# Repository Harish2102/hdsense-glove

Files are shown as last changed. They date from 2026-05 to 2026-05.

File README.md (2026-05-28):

<!-- markdownlint-disable MD041 -->
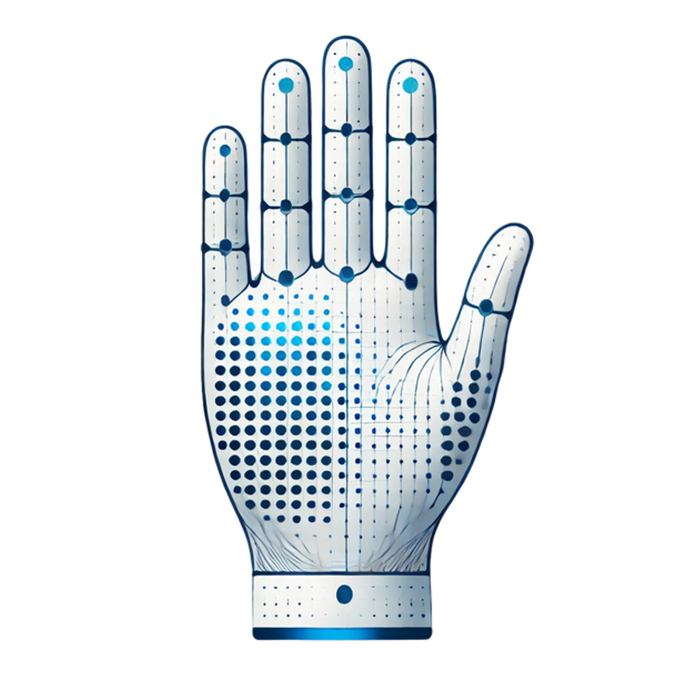
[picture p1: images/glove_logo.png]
HDSense Glove


# HDSense Glove

A high-density 32×32 pressure-sensing glove for prosthetics and haptic feedback

*Johns Hopkins University · Advanced Instruments and Systems · Fall 2024*
*Advised by Dr. Nitish Thakor and Arik Slepyan · Neuroengineering and Biomedical Instrumentation Lab*

---

## Overview

The HDSense Glove maps the full tactile surface of a hand using a **32×32 TDMA sensor array** - 1,024 individual pressure points per glove - streaming real-time contact data over serial. Designed for prosthetic hands, robotic manipulation, and human-computer interaction.

**Key specs:**

- 1,024 pressure sensors per glove (32×32 grid)
- **1000 Hz** frame rate, **20ms** latency
- **88% accuracy** detecting objects via compressed sensing
- **18× faster** than traditional raster scanning (Slepyan et al., 2024)
- Teensy 4.1 microcontroller, low-power flex-PCB design

---

## PCB Design

The glove uses a custom flex-PCB shaped to the anatomy of an average male hand (220mm length). Copper traces follow natural glove cuts with a flexible thumb extension. 32 row output pins are driven sequentially via TDMA, with a 5-bit MUX selecting across 32 columns - reducing 1,024 connections to a single analog readout channel.

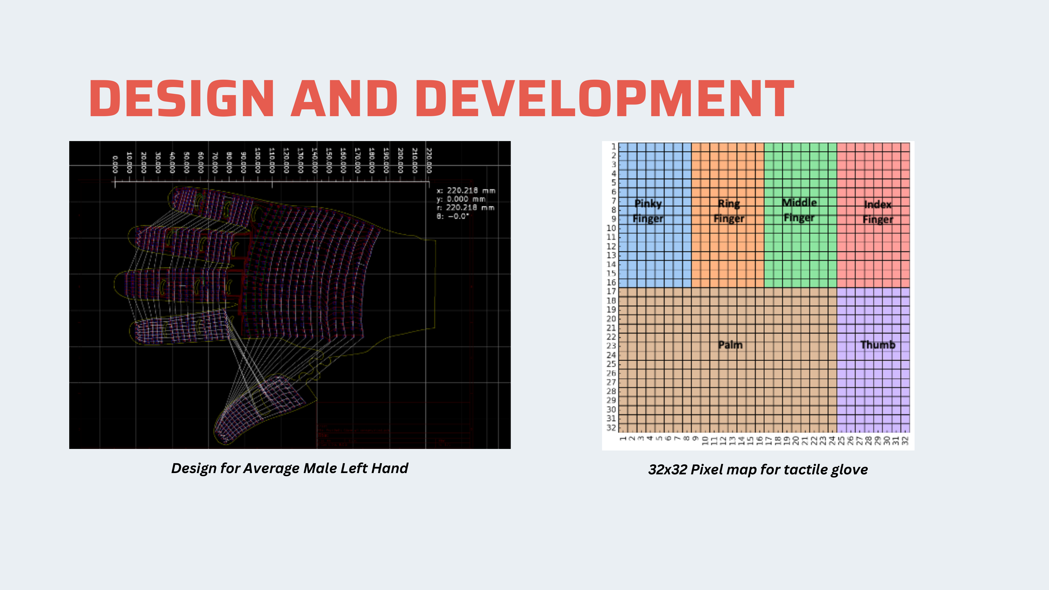
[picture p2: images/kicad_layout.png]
KiCad PCB Layout and Sensor Pixel Map


Left: KiCad flex-PCB layout shaped to the left hand geometry | Right: 32×32 sensor pixel map with finger and palm zones

The PCB was designed in KiCad with separate left-hand (LH) and right-hand (RH) variants. KiCad source files: [`hardware/LH/`](hardware/LH/) and [`hardware/RH/`](hardware/RH/)

---

## Firmware

`firmware/tdma_32x32_foot.ino` - compiled for **Teensy 4.1**

Performs a full 32×32 raster scan per loop using TDMA, outputs all 1,024 values as a comma-separated serial stream per frame. Uses `FASTRUN` and `digitalWriteFast` for maximum scan speed.

```cpp
for (int i = 0; i < 32; i++) {       // activate row
  for (int j = 0; j < 32; j++) {     // step through mux columns
    values[idx++] = analogRead(A0);  // read pressure
  }
}
```

---

## Project Poster

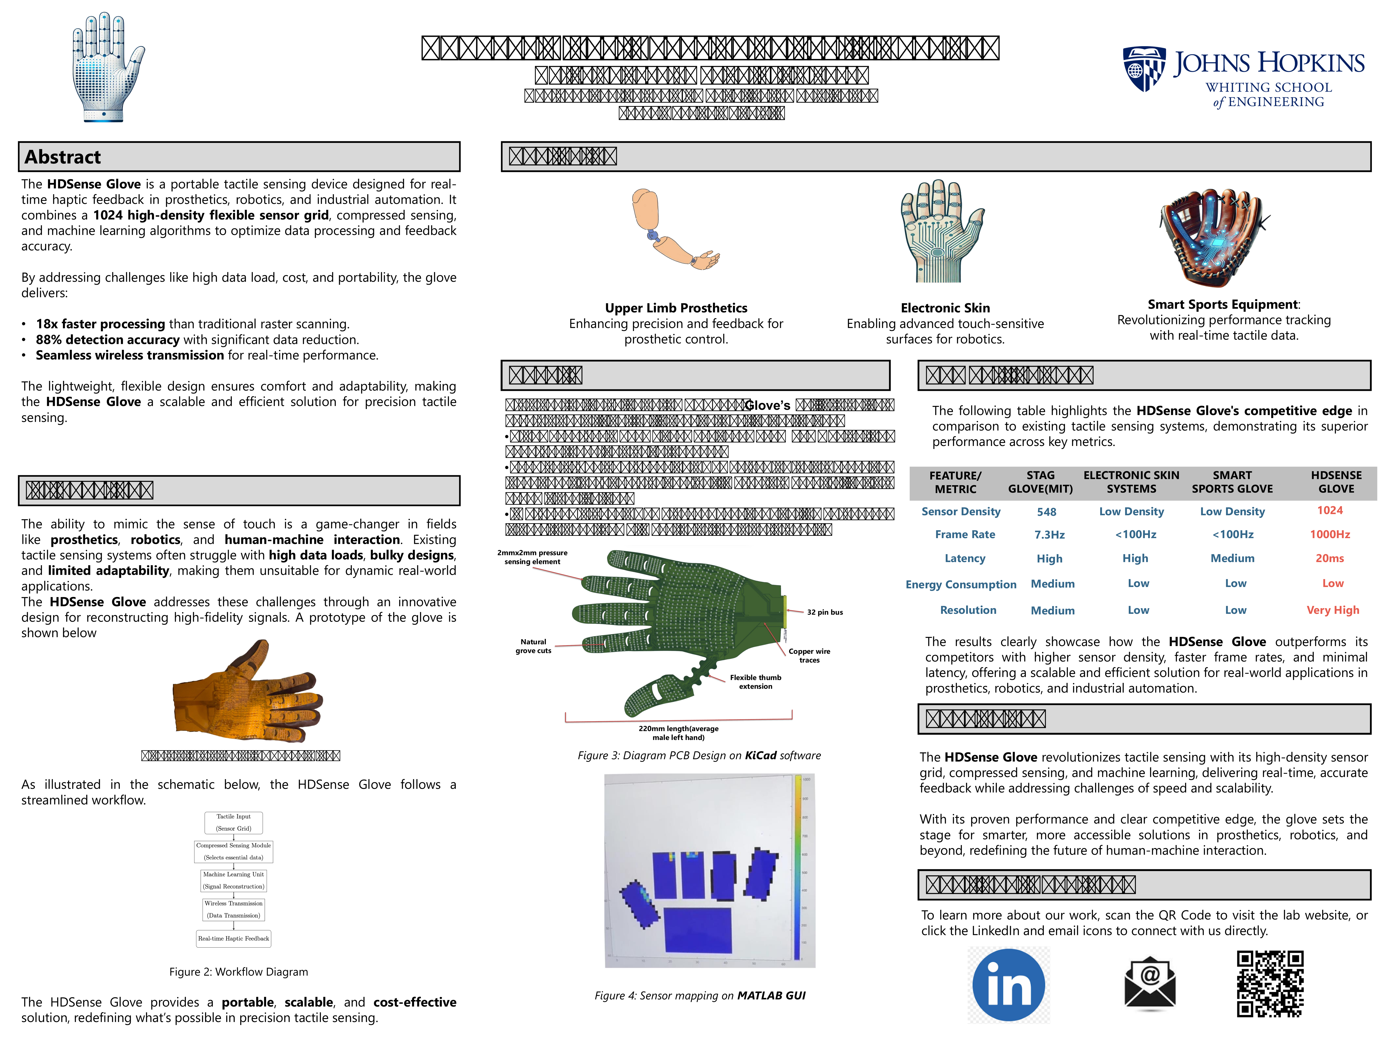
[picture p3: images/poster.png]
HDSense Glove Project Poster


Full project poster - includes KiCad PCB rendering (Fig. 3) and MATLAB sensor heatmap visualization (Fig. 4)

---

## Docs

| Document | Description |
| --- | --- |
| [Final Pitch Deck](docs/HDSense%20Glove%20Final%20Pitch.pdf) | Product pitch and system overview |
| [Project Poster](docs/Harish_Poster_Final.pdf) | Full project summary poster |

---

Harish Balasubramanian · Johns Hopkins University

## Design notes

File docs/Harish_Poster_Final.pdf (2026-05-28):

# HDSense Glove: Redesigning Tactile Sensing

## Harish Balasubramanian, Arik Slepyan

Neuroengineering and Biomedical Instrumentation Lab Johns Hopkins University

## Conclusions

The HDSense Glove revolutionizes tactile sensing with its high-density sensor grid, compressed sensing, and machine learning, delivering real-time, accurate feedback while addressing challenges of speed and scalability.

With its proven performance and clear competitive edge, the glove sets the stage for smarter, more accessible solutions in prosthetics, robotics, and beyond, redefining the future of human-machine interaction.

The HDSense Glove is a portable tactile sensing device designed for real-time haptic feedback in prosthetics, robotics, and industrial automation. It combines a 1024 high-density flexible sensor grid, compressed sensing, and machine learning algorithms to optimize data processing and feedback accuracy.

By addressing challenges like high data load, cost, and portability, the glove delivers:

- 18x faster processing than traditional raster scanning.
- 88% detection accuracy with significant data reduction.
- Seamless wireless transmission for real-time performance.

The lightweight, flexible design ensures comfort and adaptability, making the HDSense Glove a scalable and efficient solution for precision tactile sensing.

The ability to mimic the sense of touch is a game-changer in fields like prosthetics, robotics, and human-machine interaction. Existing tactile sensing systems often struggle with high data loads, bulky designs, and limited adaptability, making them unsuitable for dynamic real-world applications.
The HDSense Glove addresses these challenges through an innovative design for reconstructing high-fidelity signals. A prototype of the glove is shown below

Figure 1: Prototype of HDSense Glove

As illustrated in the schematic below, the HDSense Glove follows a streamlined workflow.

## Competitive Edge

Prototype testing validated the HDSense Glove’s ability to deliver accurate and efficient tactile sensing. Key findings include:
•High accuracy: The glove achieved over 88% detection accuracy, ensuring precise feedback.
•18x faster data processing: Compared to raster scanning techniques, the glove provides real-time performance, critical for dynamic applications.
•Improved latency: Compressed sensing algorithms reduced latency to about 20ms, much faster than other products.

## Results

## Introduction

Abstract | Application

## Additional Questions?

To learn more about our work, scan the QR Code to visit the lab website, or click the LinkedIn and email icons to connect with us directly.

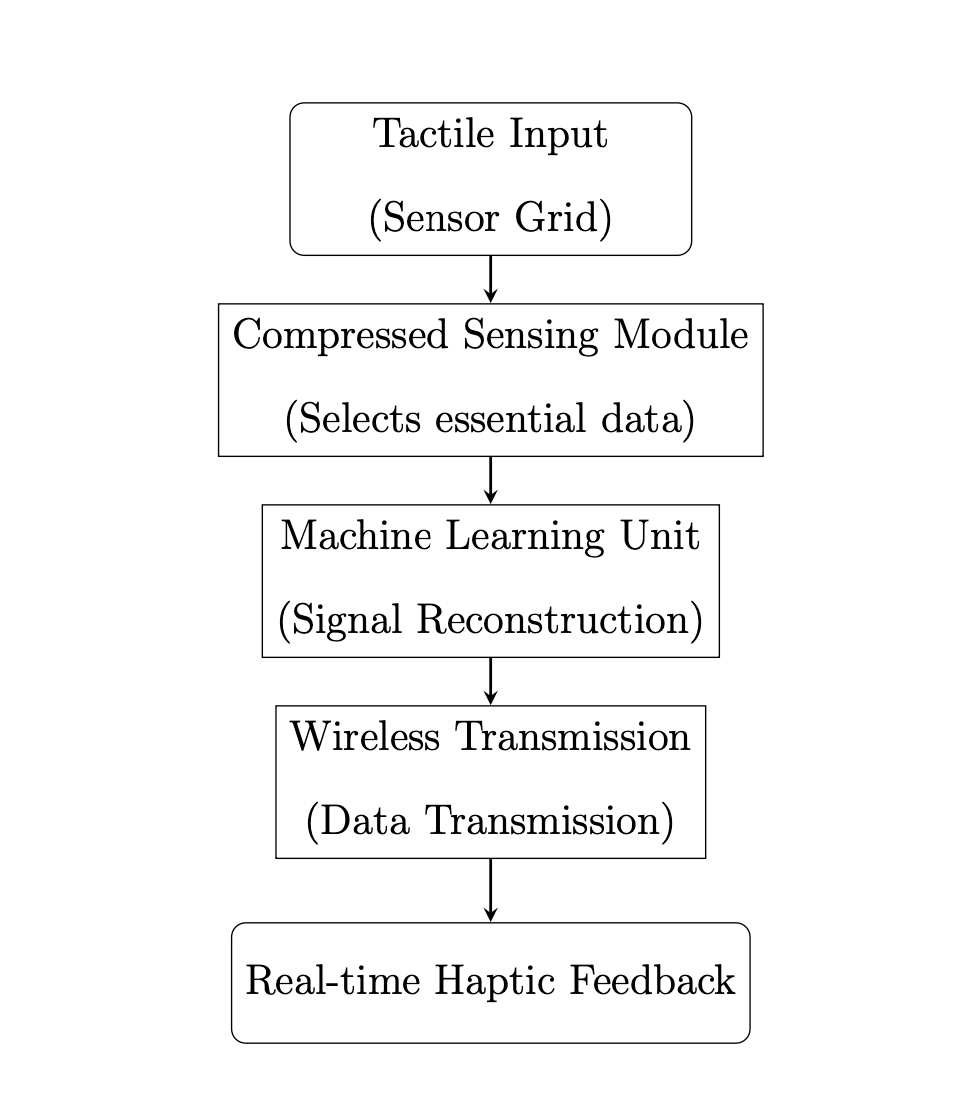
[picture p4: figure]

Figure 2: Workflow Diagram

The HDSense Glove provides a portable, scalable, and cost-effective solution, redefining what’s possible in precision tactile sensing.

STAG
GLOVE(MIT)

548

ELECTRONIC SKIN
SYSTEMS

Low Density

FEATURE/
METRIC

Sensor Density

SMART
SPORTS GLOVE

Low Density

Frame Rate | | <100Hz | <100Hz | HDSENSE GLOVE
| | | | 1024
| 7.3Hz | | | 1000Hz
Latency | High | High | Medium | 20ms
Energy Consumption | Medium | Low | Low | Low
Resolution | Medium | Low | Low | Very High

The following table highlights the HDSense Glove's competitive edge in comparison to existing tactile sensing systems, demonstrating its superior performance across key metrics.

The results clearly showcase how the HDSense Glove outperforms its competitors with higher sensor density, faster frame rates, and minimal latency, offering a scalable and efficient solution for real-world applications in prosthetics, robotics, and industrial automation.

Upper Limb Prosthetics
Enhancing precision and feedback for prosthetic control.

Electronic Skin
Enabling advanced touch-sensitive surfaces for robotics.

Smart Sports Equipment:
Revolutionizing performance tracking with real-time tactile data.

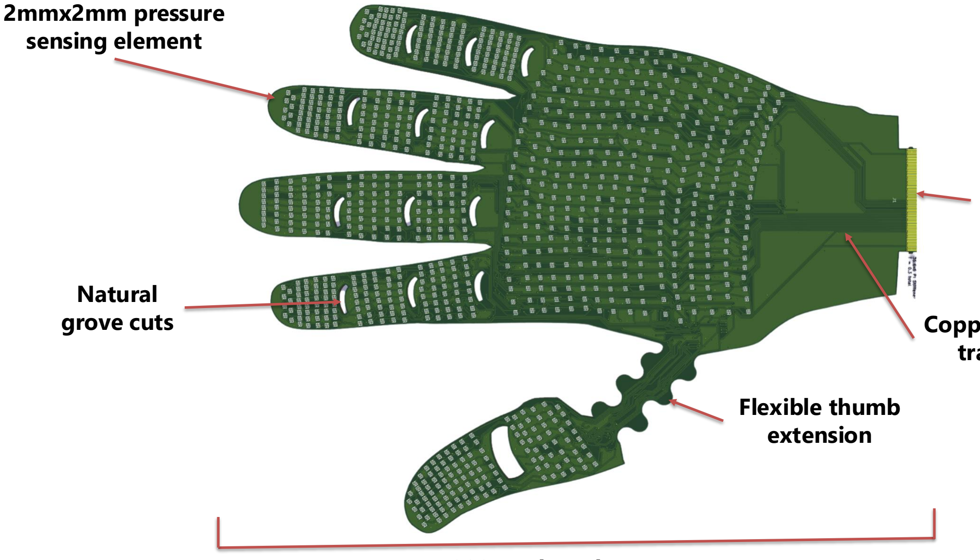
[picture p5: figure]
2mmx2mm pressure sensing element; Natural grove cuts; Flexible thumb extension

Figure 3: Diagram PCB Design on KiCad software

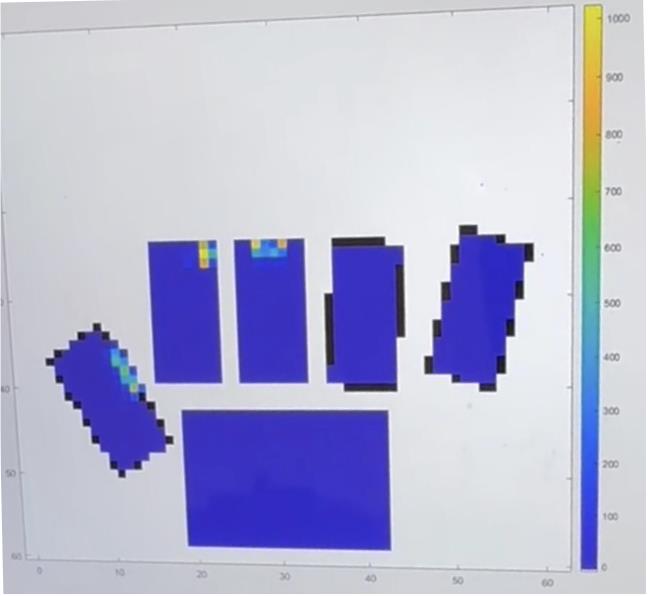
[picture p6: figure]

Figure 4: Sensor mapping on MATLAB GUI

220mm length(average
male left hand)

### 32 pin bus

Copper wire
traces

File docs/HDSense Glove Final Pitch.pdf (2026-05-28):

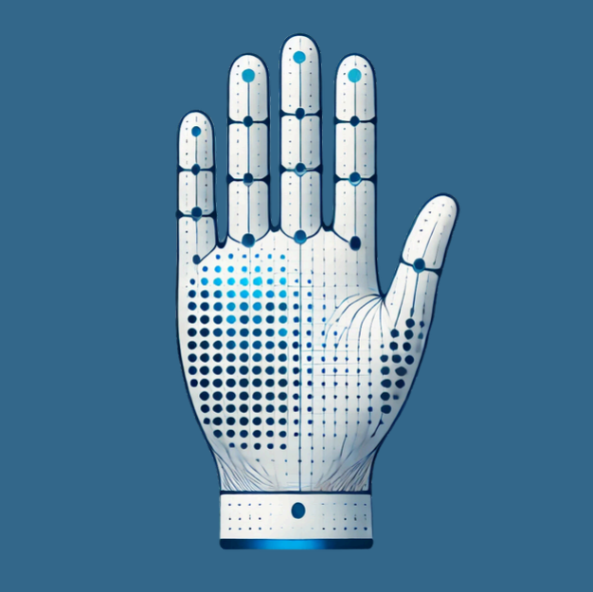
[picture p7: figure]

# HDSENSE GLOVE

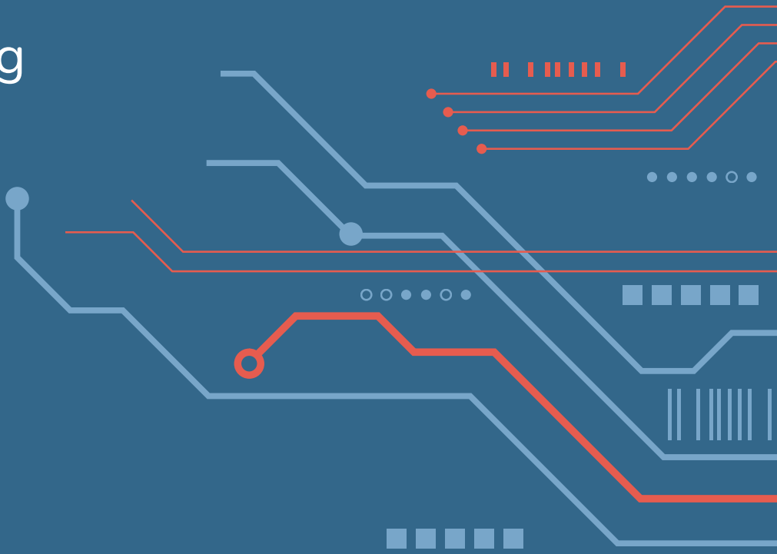
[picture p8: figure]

Redefining Tactile feedback with Compressed Sensing

By Harish Balasubramanian
Graduate Student, Biomedical Engineering, Johns Hopkins University Under the guidance of Dr. Nitish Thakor and Arik Slepyan (Neuroengineering and Biomedical Instrumentation Lab)

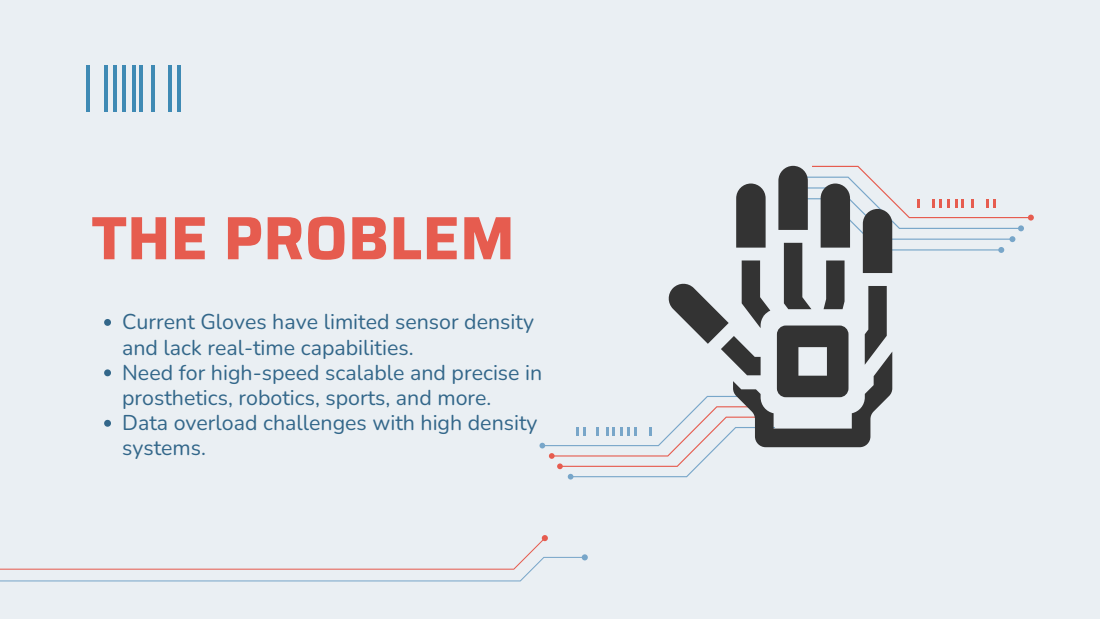
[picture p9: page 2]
THE PROBLEM

Current Gloves have limited sensor density
and lack real-time capabilities.
Need for high-speed scalable and precise in
prosthetics, robotics, sports, and more.
Data overload challenges with high density
systems.

# THE INNOVATION

1024 Sensors

32x32 High Density
Sensor Grid

88% accuracy
Detecting objects

Compressed Sensing
Venus is the second
planet from the Sun

Low power
Low powered Teensy
Board

Real-time
20ms detecting
speed after contact

18X faster
Subsampling method*
over Raster scanning

*Slepyan et al., 2024.

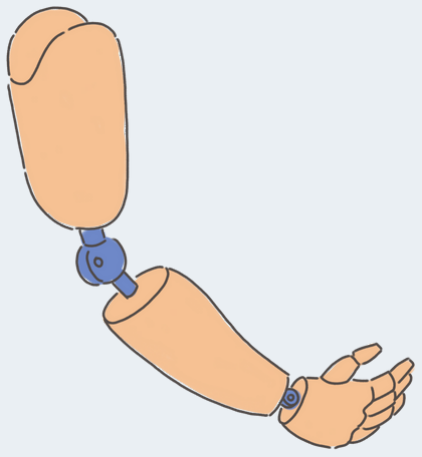
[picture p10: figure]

Upper Limb Prosthetics
1.1 Billion* in 2021,
growing at 5.4% CAGR

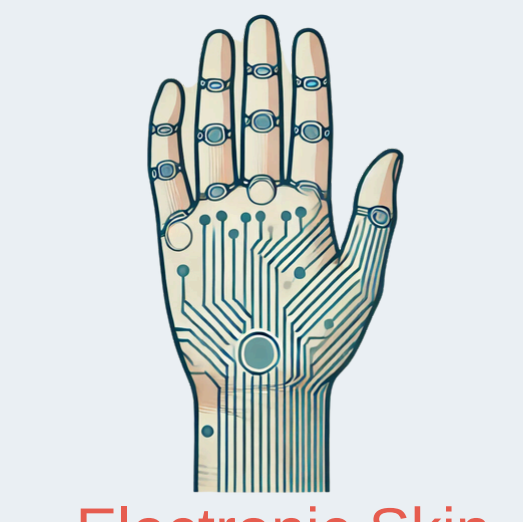
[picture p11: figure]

Electronic Skin
19.6 Billion* by 2029

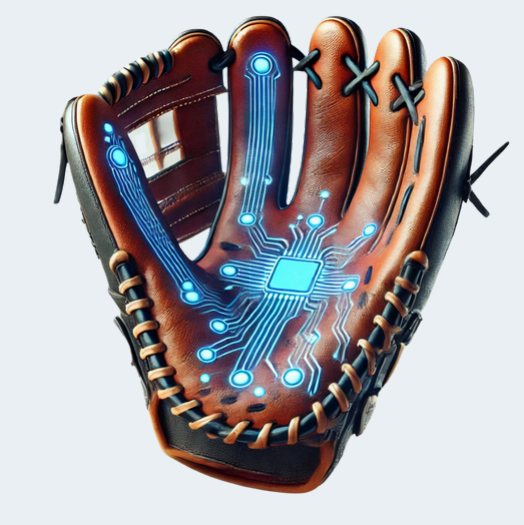
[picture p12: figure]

Smart Sports Equipment
2.6 Billion* in 2021

# MARKET ANALYSIS

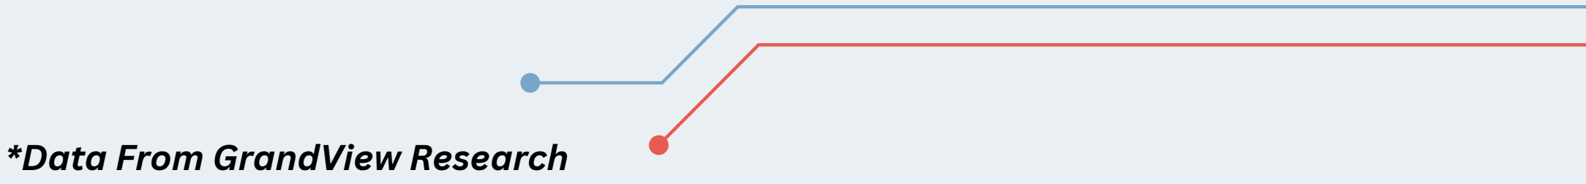
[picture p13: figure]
*Data From GrandView Research

# COMPETITIVE EDGE

STAG
GLOVE(MIT)
548

ELECTRONIC SKIN
SYSTEMS
Low Density

FEATURE/
METRIC
Sensor Density

SMART SPORTS
GLOVE
Low Density
Frame Rate | | <100Hz | <100Hz | HDSENSE GLOVE
| | | | 1024
| 7.3Hz | | | 1000Hz
Latency | High | High | Medium | 20ms
Energy Consumption | Medium | Low | Low | Low
Resolution | Medium | Low | Low | Very High

# DESIGN AND DEVELOPMENT

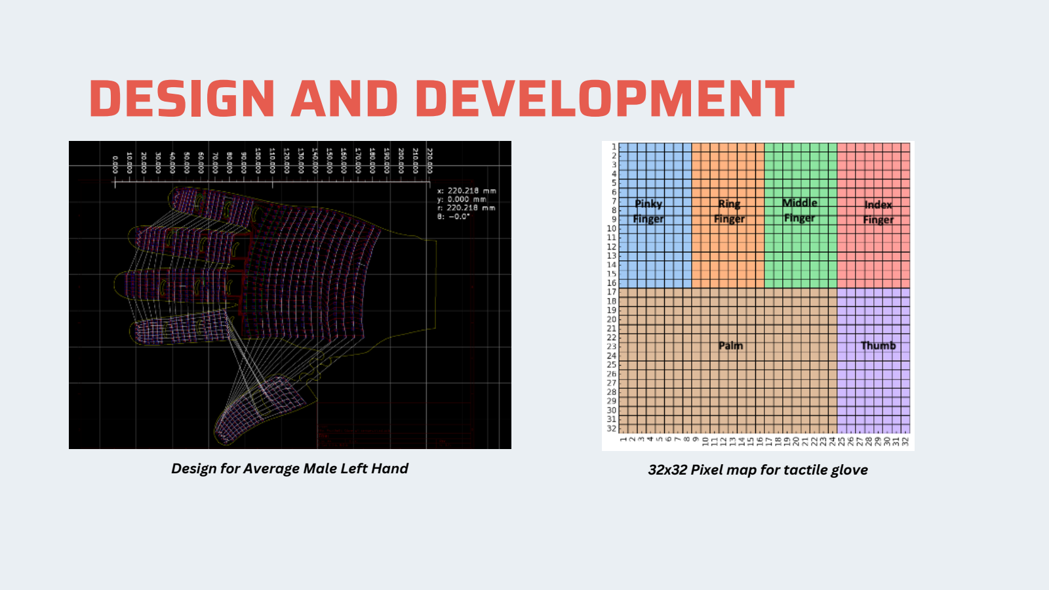
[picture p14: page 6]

Design for Average Male Left Hand | 32x32 Pixel map for tactile glove

# PATENT STATUS

Patent for Compressed Sensing Technology using ACTS and Machine Learning is pending approval and refinement.

Key Claims:
High-Speed Tactile Sensing:
Integration of compressed sensing to reduce data overload and latency.

Machine Learning-Driven Reconstruction:
Uses a learned tactile dictionary for precise and efficient signal reconstruction.

Scalable and Cost-Effective:
Adaptable for multi-industry applications in prosthetics, robotics, and sports.

# PRICING

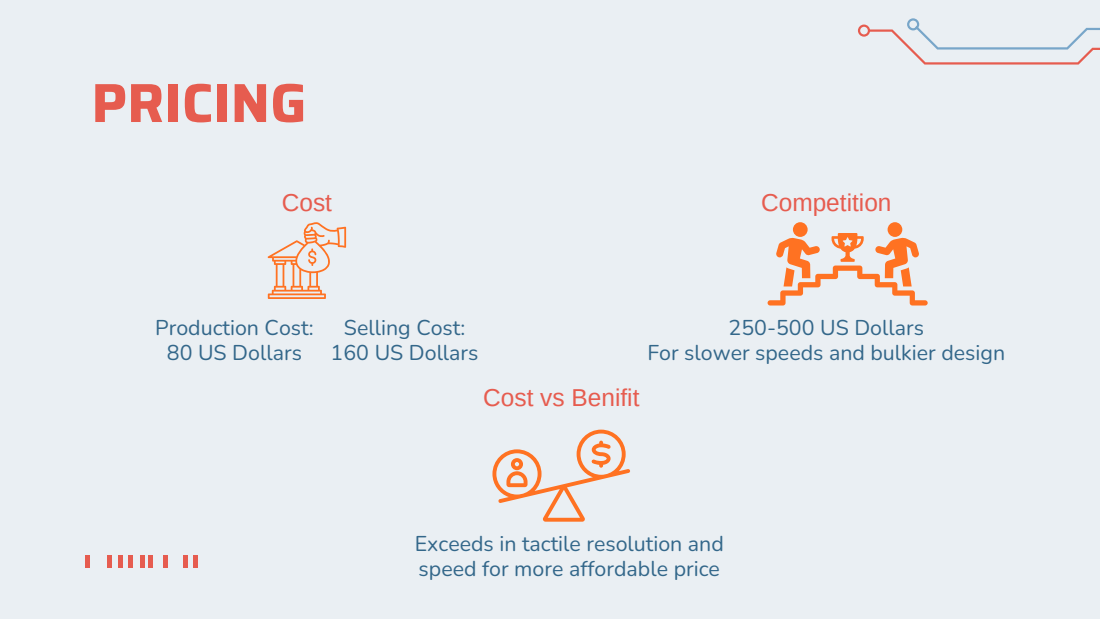
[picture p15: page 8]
Selling Cost: 160 US Dollars; Cost; Production Cost: 80 US Dollars; Competition

250-500 US Dollars
For slower speeds and bulkier design

Cost vs Benifit

Exceeds in tactile resolution and
speed for more affordable price

# WHERE DO WE GO FROM HERE?

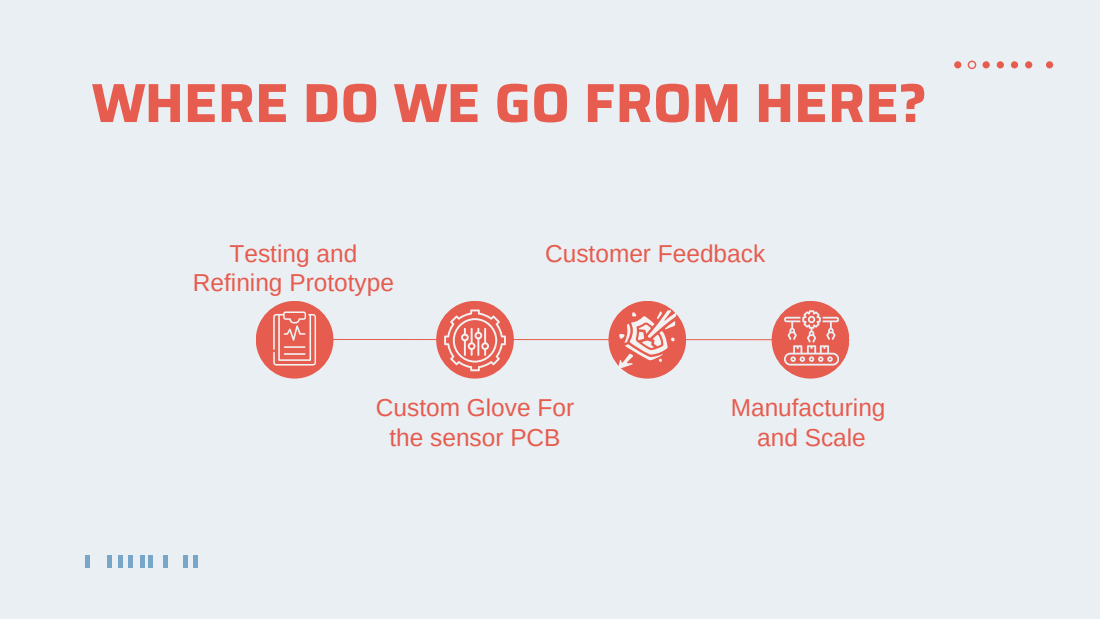
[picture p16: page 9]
Manufacturing and Scale; Testing and Refining Prototype; Customer Feedback

Custom Glove For
the sensor PCB

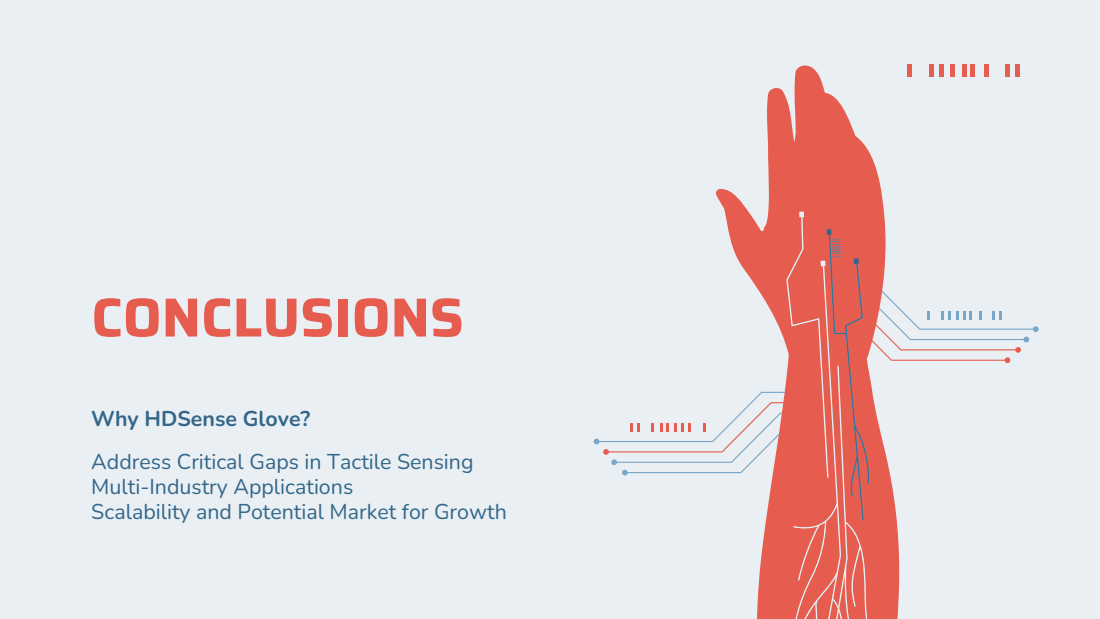
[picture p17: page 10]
CONCLUSIONS

Why HDSense Glove?
Address Critical Gaps in Tactile Sensing
Multi-Industry Applications
Scalability and Potential Market for Growth

# THANKS

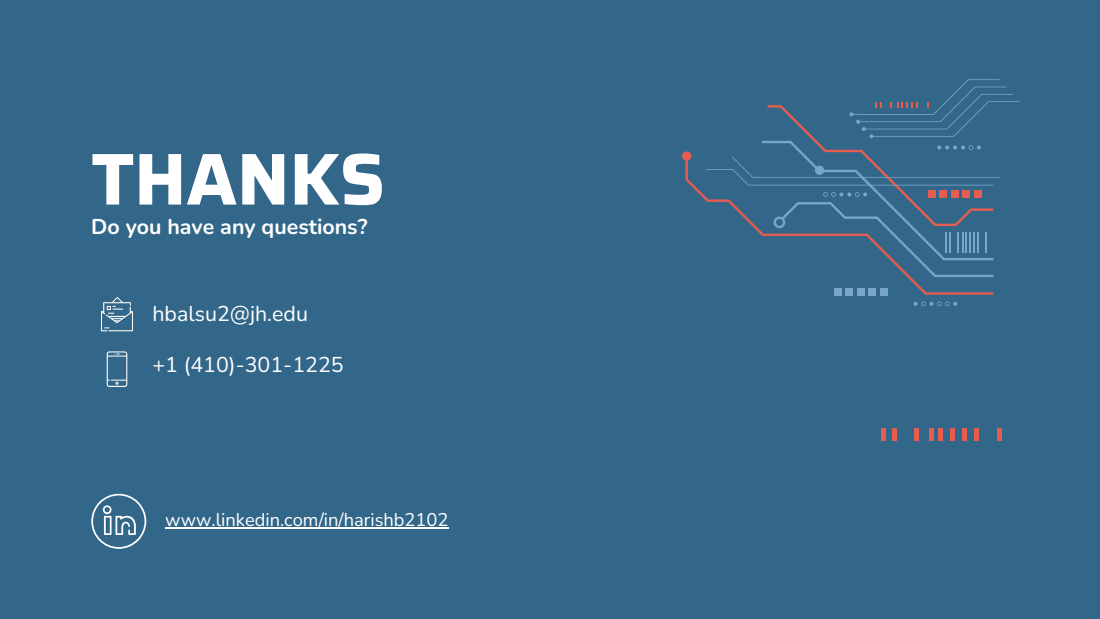
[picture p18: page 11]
hbalsu2@jh.edu

Do you have any questions?

www.linkedin.com/in/harishb2102

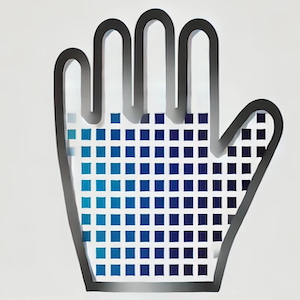
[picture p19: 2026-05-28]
images/HDSenseGlove.jpg

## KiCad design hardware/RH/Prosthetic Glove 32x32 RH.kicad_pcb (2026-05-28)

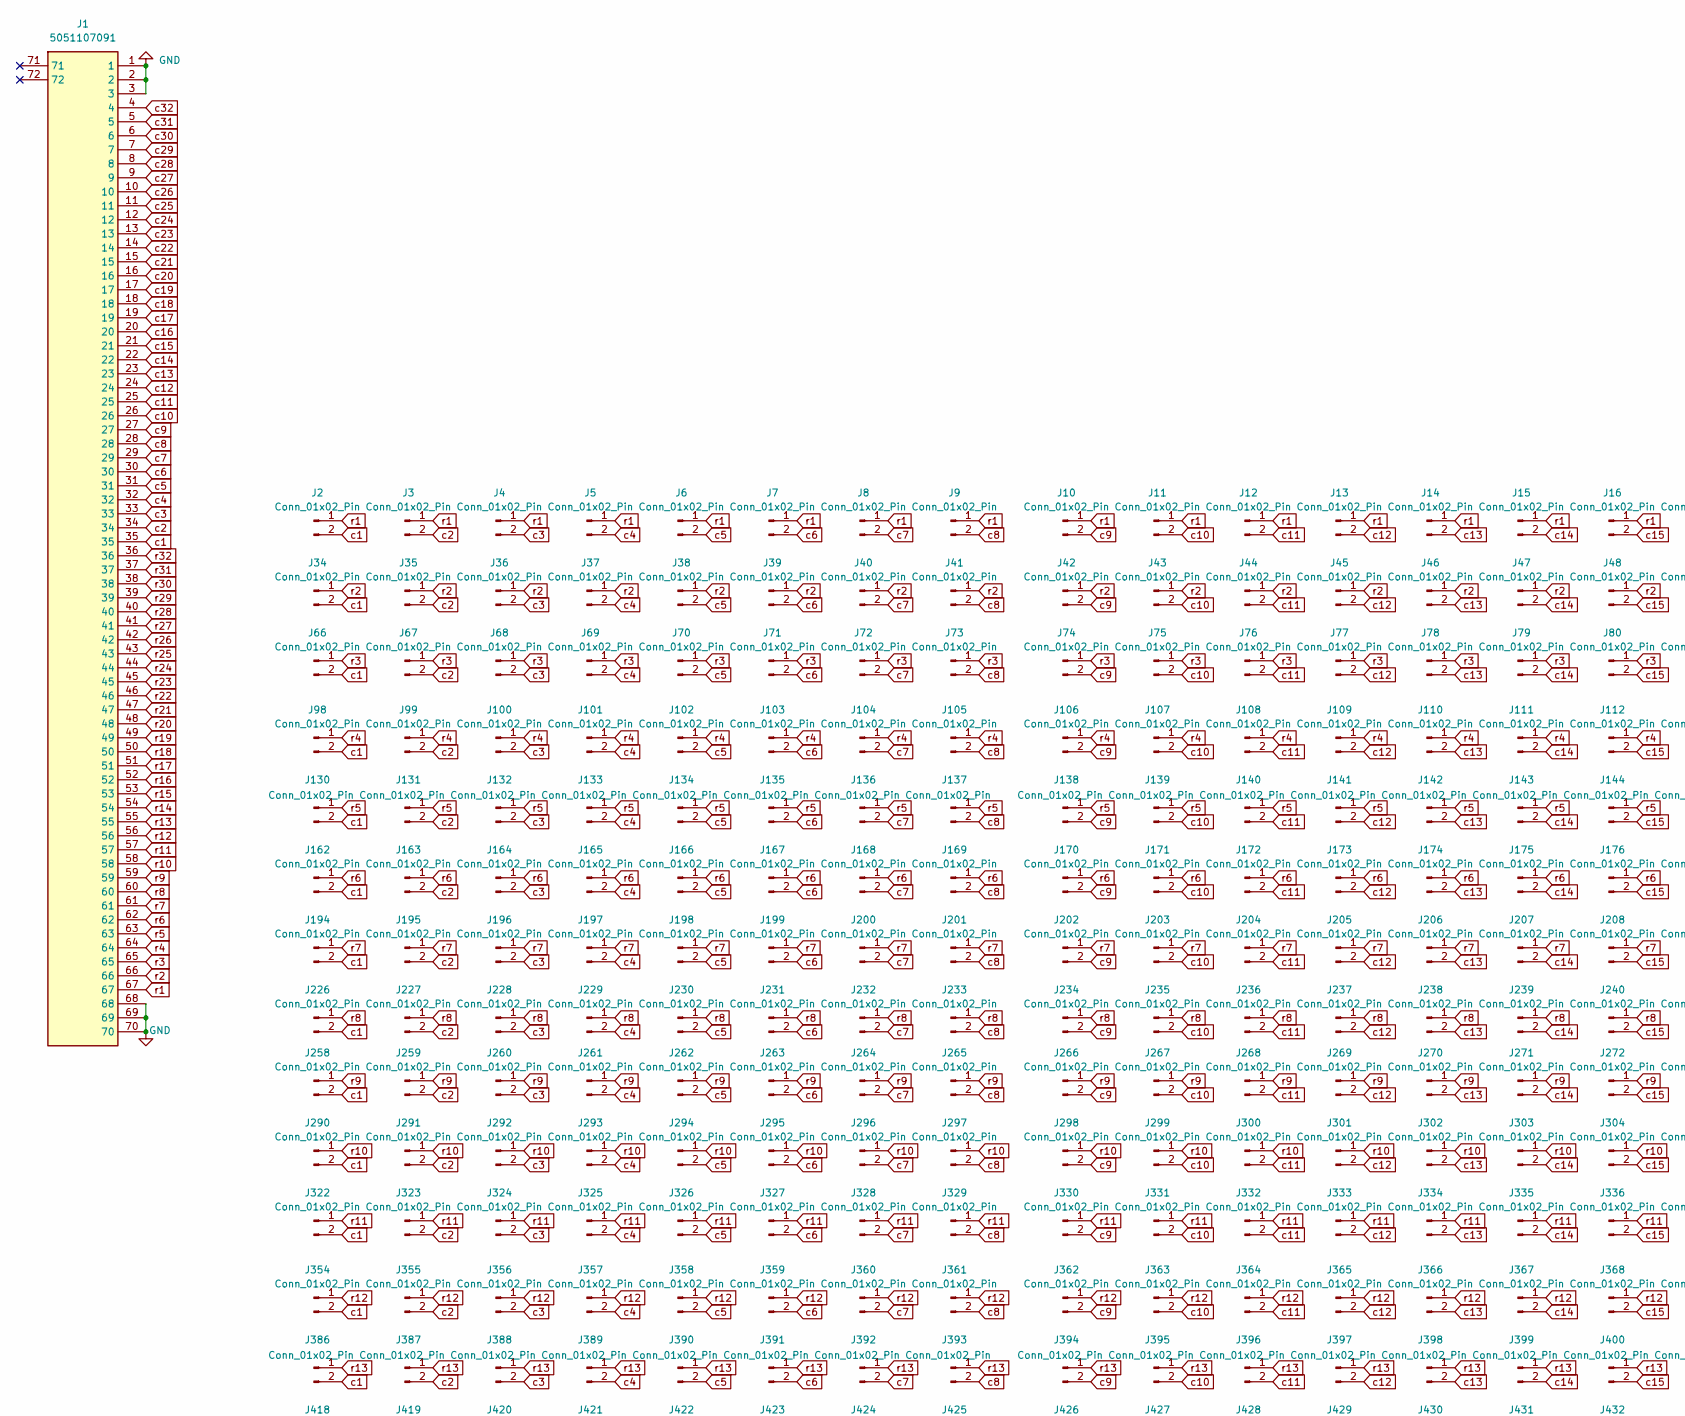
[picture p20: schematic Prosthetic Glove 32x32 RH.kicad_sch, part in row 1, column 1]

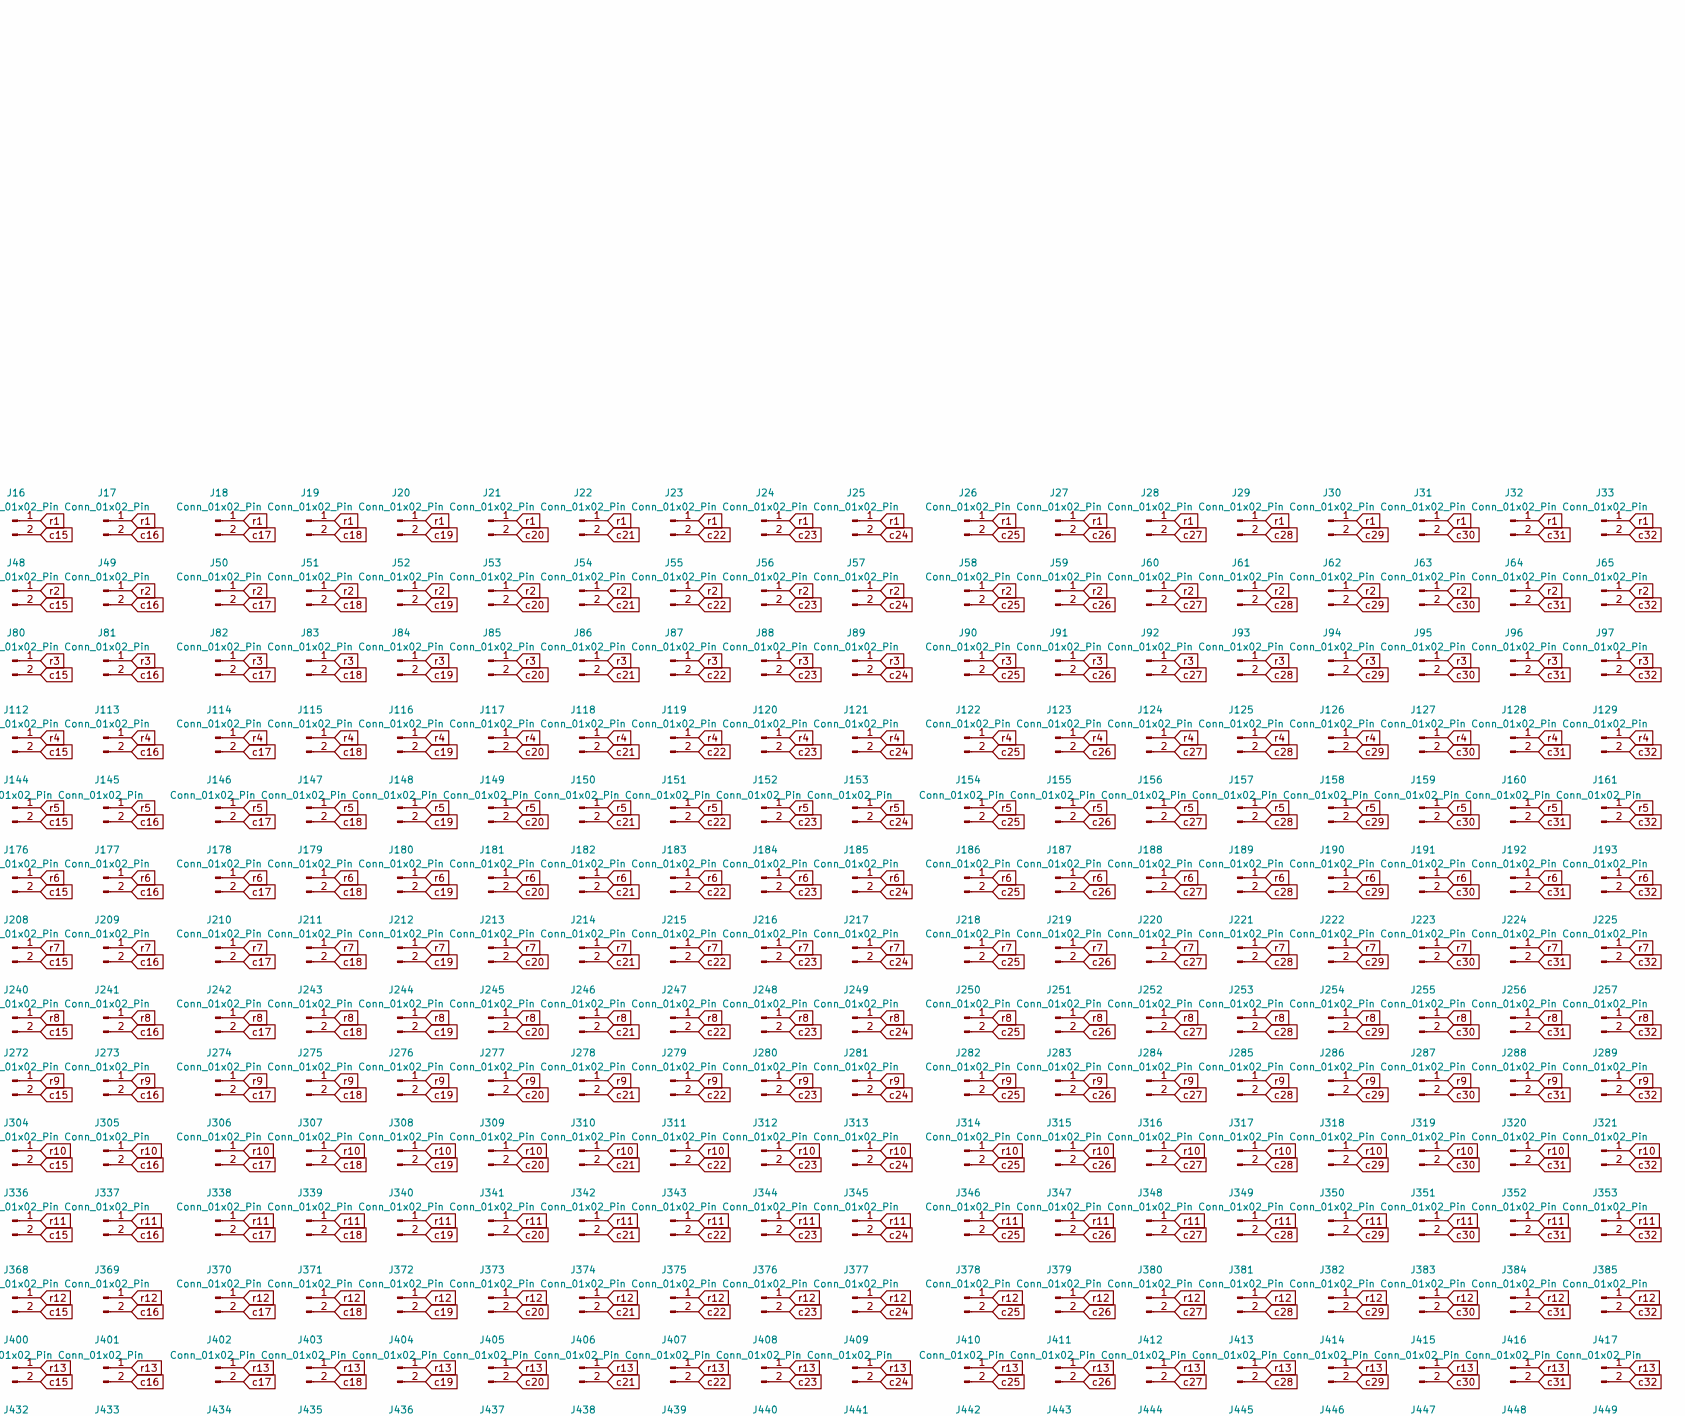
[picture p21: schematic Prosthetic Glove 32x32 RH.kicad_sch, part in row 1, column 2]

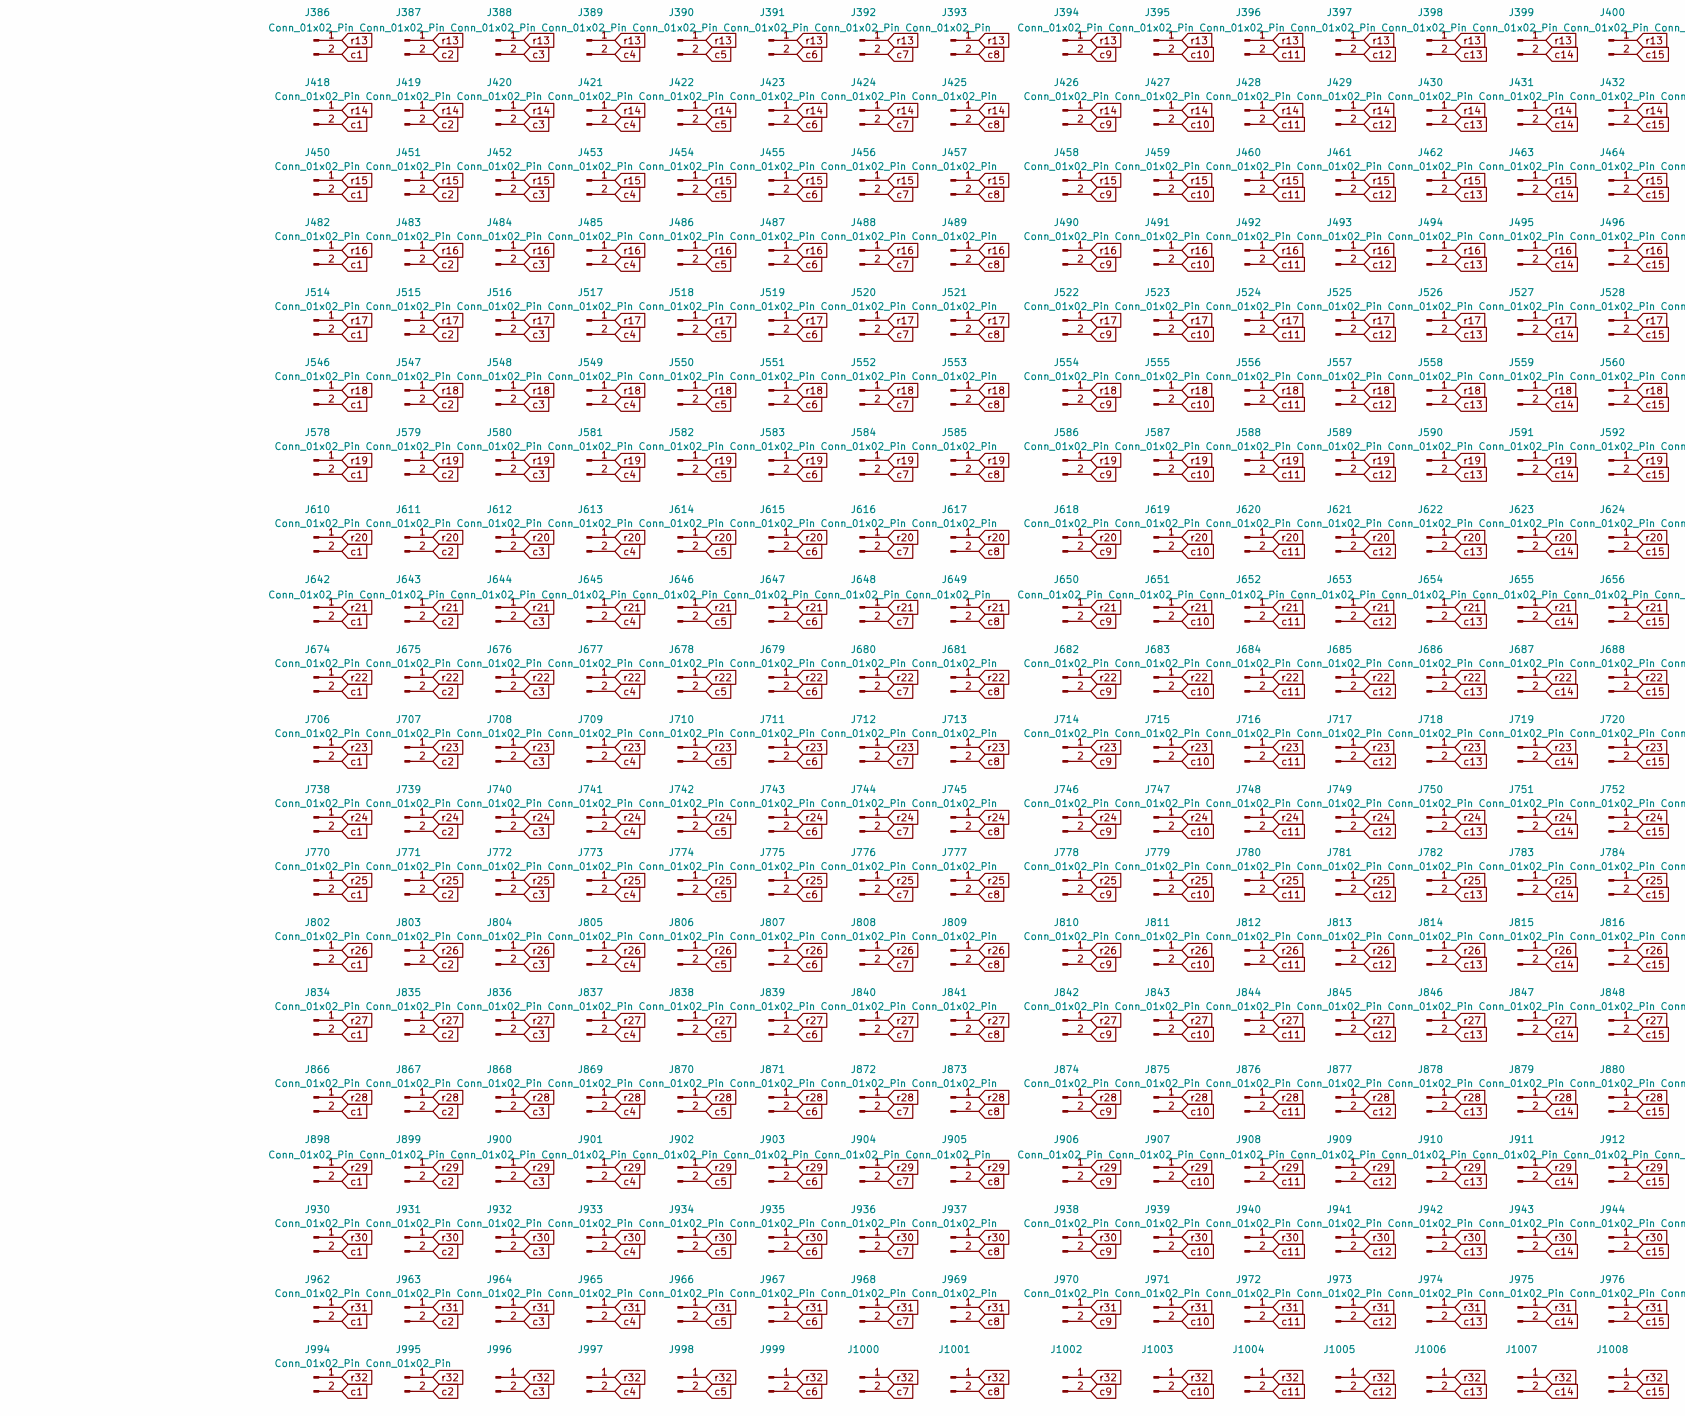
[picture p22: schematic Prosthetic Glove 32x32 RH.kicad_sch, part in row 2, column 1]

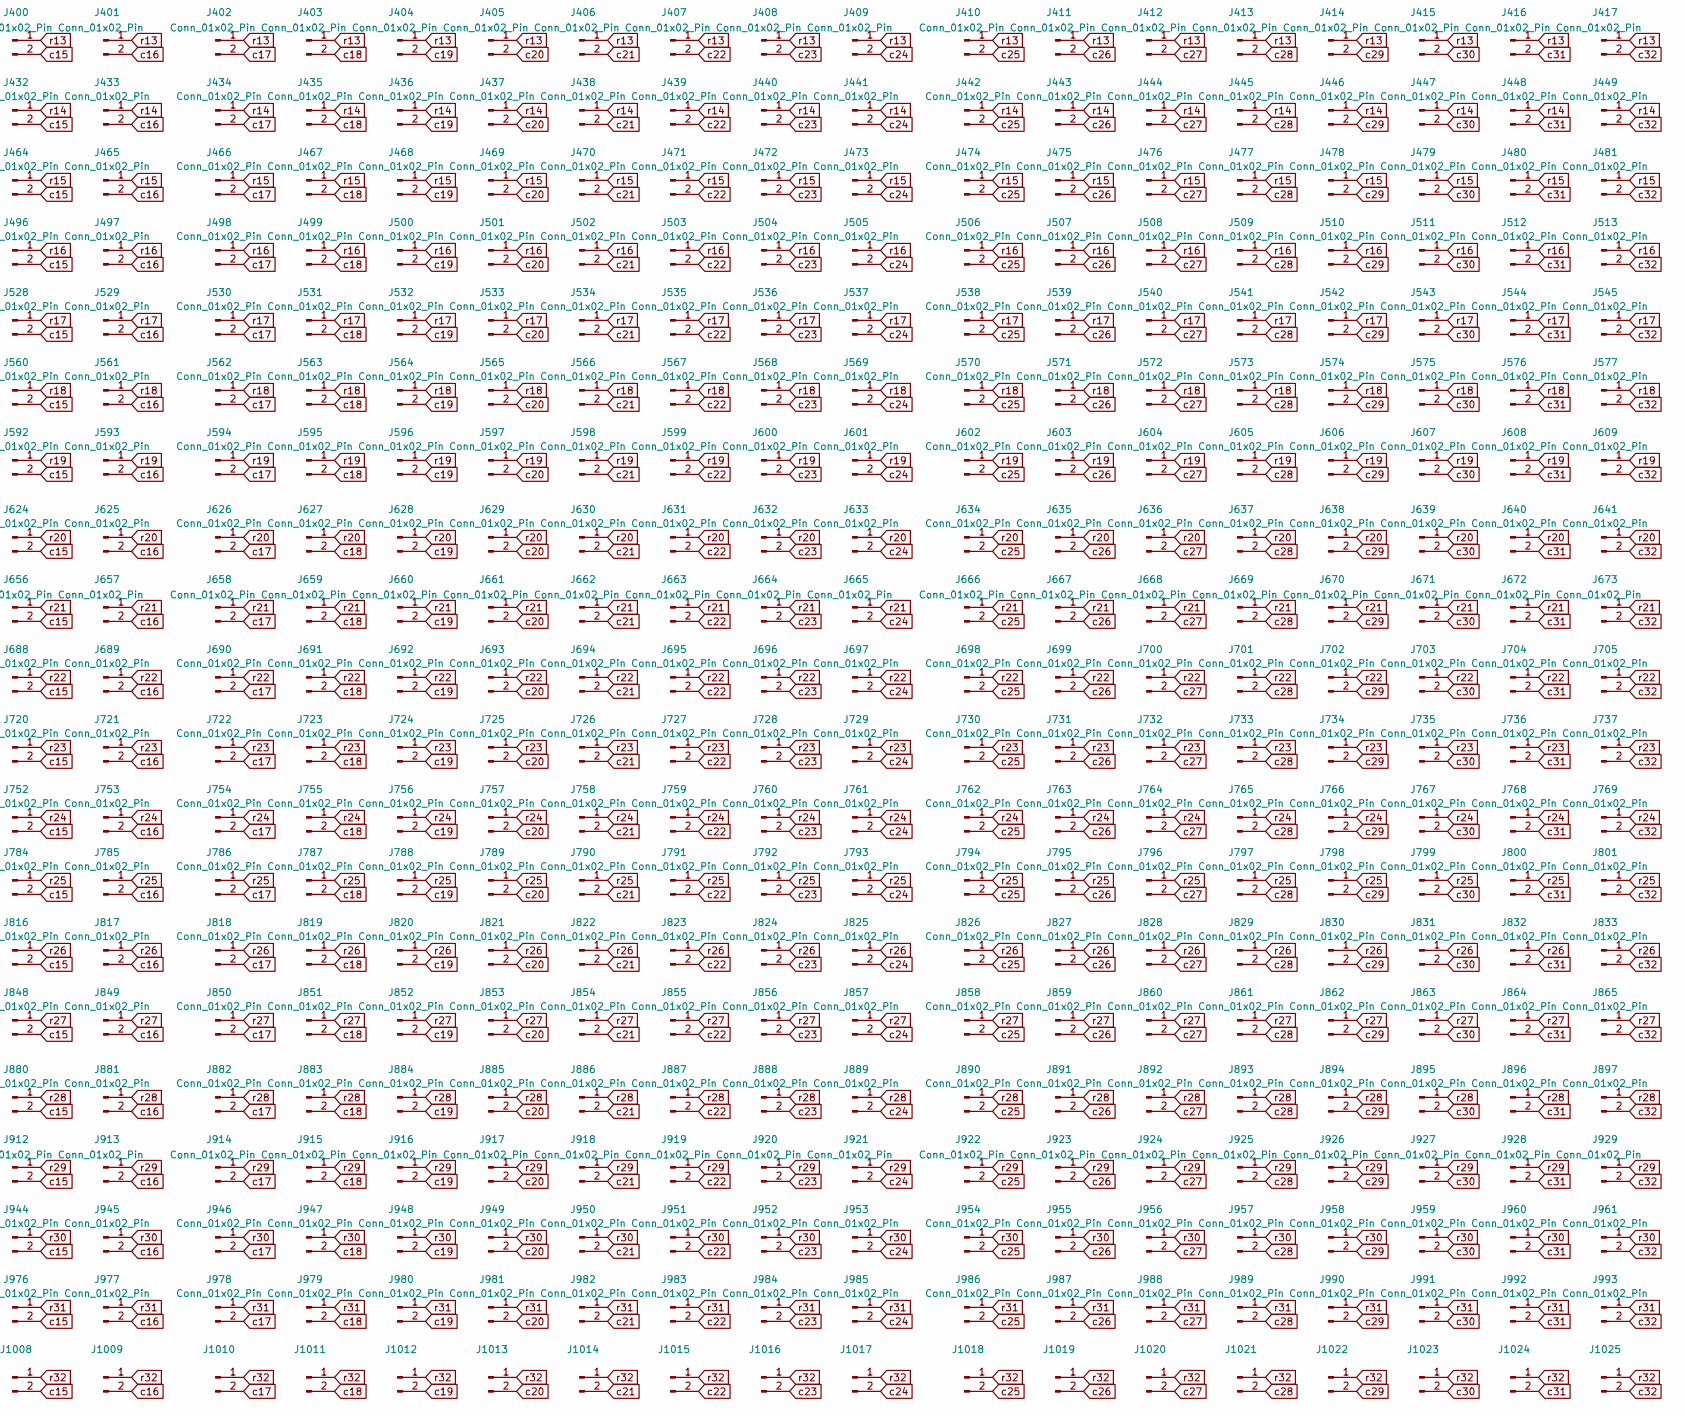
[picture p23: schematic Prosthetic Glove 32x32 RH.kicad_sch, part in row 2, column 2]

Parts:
J1: 5051107091; 70_pos_0.5mm_FPC; Manufacturer_Part_Number 5051107091
J2, J3, J4, J5, J6, J7, J8, J9, J10, J11, J12, J13, J14, J15, J16, J17, J18, J19, J20, J21, J22, J23, J24, J25, J26, J27, J28, J29, J30, J31, J32, J33, J34, J35, J36, J37, J38, J39, J40, J41, J42, J43, J44, J45, J46, J47, J48, J49, J50, J51, J52, J53, J54, J55, J56, J57, J58, J59, J60, J61, J62, J63, J64, J65, J66, J67, J68, J69, J70, J71, J72, J73, J74, J75, J76, J77, J78, J79, J80, J81, J82, J83, J84, J85, J86, J87, J88, J89, J90, J91, J92, J93, J94, J95, J96, J97, J98, J99, J100, J101, J102, J103, J104, J105, J106, J107, J108, J109, J110, J111, J112, J113, J114, J115, J116, J117, J118, J119, J120, J121, J122, J123, J124, J125, J126, J127, J128, J129, J130, J131, J132, J133, J134, J135, J136, J137, J138, J139, J140, J141, J142, J143, J144, J145, J146, J147, J148, J149, J150, J151, J152, J153, J154, J155, J156, J157, J158, J159, J160, J161, J162, J163, J164, J165, J166, J167, J168, J169, J170, J171, J172, J173, J174, J175, J176, J177, J178, J179, J180, J181, J182, J183, J184, J185, J186, J187, J188, J189, J190, J191, J192, J193, J194, J195, J196, J197, J198, J199, J200, J201, J202, J203, J204, J205, J206, J207, J208, J209, J210, J211, J212, J213, J214, J215, J216, J217, J218, J219, J220, J221, J222, J223, J224, J225, J226, J227, J228, J229, J230, J231, J232, J233, J234, J235, J236, J237, J238, J239, J240, J241, J242, J243, J244, J245, J246, J247, J248, J249, J250, J251, J252, J253, J254, J255, J256, J257, J258, J259, J260, J261, J262, J263, J264, J265, J266, J267, J268, J269, J270, J271, J272, J273, J274, J275, J276, J277, J278, J279, J280, J281, J282, J283, J284, J285, J286, J287, J288, J289, J290, J291, J292, J293, J294, J295, J296, J297, J298, J299, J300, J301, J302, J303, J304, J305, J306, J307, J308, J309, J310, J311, J312, J313, J314, J315, J316, J317, J318, J319, J320, J321, J322, J323, J324, J325, J326, J327, J328, J329, J330, J331, J332, J333, J334, J335, J336, J337, J338, J339, J340, J341, J342, J343, J344, J345, J346, J347, J348, J349, J350, J351, J352, J353, J354, J355, J356, J357, J358, J359, J360, J361, J362, J363, J364, J365, J366, J367, J368, J369, J370, J371, J372, J373, J374, J375, J376, J377, J378, J379, J380, J381, J382, J383, J384, J385, J386, J387, J388, J389, J390, J391, J392, J393, J394, J395, J396, J397, J398, J399, J400, J401, J402, J403, J404, J405, J406, J407, J408, J409, J410, J411, J412, J413, J414, J415, J416, J417, J418, J419, J420, J421, J422, J423, J424, J425, J426, J427, J428, J429, J430, J431, J432, J433, J434, J435, J436, J437, J438, J439, J440, J441, J442, J443, J444, J445, J446, J447, J448, J449, J450, J451, J452, J453, J454, J455, J456, J457, J458, J459, J460, J461, J462, J463, J464, J465, J466, J467, J468, J469, J470, J471, J472, J473, J474, J475, J476, J477, J478, J479, J480, J481, J482, J483, J484, J485, J486, J487, J488, J489, J490, J491, J492, J493, J494, J495, J496, J497, J498, J499, J500, J501, J502, J503, J504, J505, J506, J507, J508, J509, J510, J511, J512, J513, J514, J515, J516, J517, J518, J519, J520, J521, J522, J523, J524, J525, J526, J527, J528, J529, J530, J531, J532, J533, J534, J535, J536, J537, J538, J539, J540, J541, J542, J543, J544, J545, J546, J547, J548, J549, J550, J551, J552, J553, J554, J555, J556, J557, J558, J559, J560, J561, J562, J563, J564, J565, J566, J567, J568, J569, J570, J571, J572, J573, J574, J575, J576, J577, J578, J579, J580, J581, J582, J583, J584, J585, J586, J587, J588, J589, J590, J591, J592, J593, J594, J595, J596, J597, J598, J599, J600, J601, J602, J603, J604, J605, J606, J607, J608, J609, J610, J611, J612, J613, J614, J615, J616, J617, J618, J619, J620, J621, J622, J623, J624, J625, J626, J627, J628, J629, J630, J631, J632, J633, J634, J635, J636, J637, J638, J639, J640, J641, J642, J643, J644, J645, J646, J647, J648, J649, J650, J651, J652, J653, J654, J655, J656, J657, J658, J659, J660, J661, J662, J663, J664, J665, J666, J667, J668, J669, J670, J671, J672, J673, J674, J675, J676, J677, J678, J679, J680, J681, J682, J683, J684, J685, J686, J687, J688, J689, J690, J691, J692, J693, J694, J695, J696, J697, J698, J699, J700, J701, J702, J703, J704, J705, J706, J707, J708, J709, J710, J711, J712, J713, J714, J715, J716, J717, J718, J719, J720, J721, J722, J723, J724, J725, J726, J727, J728, J729, J730, J731, J732, J733, J734, J735, J736, J737, J738, J739, J740, J741, J742, J743, J744, J745, J746, J747, J748, J749, J750, J751, J752, J753, J754, J755, J756, J757, J758, J759, J760, J761, J762, J763, J764, J765, J766, J767, J768, J769, J770, J771, J772, J773, J774, J775, J776, J777, J778, J779, J780, J781, J782, J783, J784, J785, J786, J787, J788, J789, J790, J791, J792, J793, J794, J795, J796, J797, J798, J799, J800, J801, J802, J803, J804, J805, J806, J807, J808, J809, J810, J811, J812, J813, J814, J815, J816, J817, J818, J819, J820, J821, J822, J823, J824, J825, J826, J827, J828, J829, J830, J831, J832, J833, J834, J835, J836, J837, J838, J839, J840, J841, J842, J843, J844, J845, J846, J847, J848, J849, J850, J851, J852, J853, J854, J855, J856, J857, J858, J859, J860, J861, J862, J863, J864, J865, J866, J867, J868, J869, J870, J871, J872, J873, J874, J875, J876, J877, J878, J879, J880, J881, J882, J883, J884, J885, J886, J887, J888, J889, J890, J891, J892, J893, J894, J895, J896, J897, J898, J899, J900, J901, J902, J903, J904, J905, J906, J907, J908, J909, J910, J911, J912, J913, J914, J915, J916, J917, J918, J919, J920, J921, J922, J923, J924, J925, J926, J927, J928, J929, J930, J931, J932, J933, J934, J935, J936, J937, J938, J939, J940, J941, J942, J943, J944, J945, J946, J947, J948, J949, J950, J951, J952, J953, J954, J955, J956, J957, J958, J959, J960, J961, J962, J963, J964, J965, J966, J967, J968, J969, J970, J971, J972, J973, J974, J975, J976, J977, J978, J979, J980, J981, J982, J983, J984, J985, J986, J987, J988, J989, J990, J991, J992, J993, J994, J995, J996, J997, J998, J999, J1000, J1001, J1002, J1003, J1004, J1005, J1006, J1007, J1008, J1009, J1010, J1011, J1012, J1013, J1014, J1015, J1016, J1017, J1018, J1019, J1020, J1021, J1022, J1023, J1024, J1025: Conn_01x02_Pin; sensor_2mmx2mm

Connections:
GND: J1.1, J1.2, J1.3, J1.68, J1.69, J1.70
c1: J1.35, J2.2, J34.2, J66.2, J98.2, J130.2, J162.2, J194.2, J226.2, J258.2, J290.2, J322.2, J354.2, J386.2, J418.2, J450.2, J482.2, J514.2, J546.2, J578.2, J610.2, J642.2, J674.2, J706.2, J738.2, J770.2, J802.2, J834.2, J866.2, J898.2, J930.2, J962.2, J994.2
c2: J1.34, J3.2, J35.2, J67.2, J99.2, J131.2, J163.2, J195.2, J227.2, J259.2, J291.2, J323.2, J355.2, J387.2, J419.2, J451.2, J483.2, J515.2, J547.2, J579.2, J611.2, J643.2, J675.2, J707.2, J739.2, J771.2, J803.2, J835.2, J867.2, J899.2, J931.2, J963.2, J995.2
c3: J1.33, J4.2, J36.2, J68.2, J100.2, J132.2, J164.2, J196.2, J228.2, J260.2, J292.2, J324.2, J356.2, J388.2, J420.2, J452.2, J484.2, J516.2, J548.2, J580.2, J612.2, J644.2, J676.2, J708.2, J740.2, J772.2, J804.2, J836.2, J868.2, J900.2, J932.2, J964.2, J996.2
c4: J1.32, J5.2, J37.2, J69.2, J101.2, J133.2, J165.2, J197.2, J229.2, J261.2, J293.2, J325.2, J357.2, J389.2, J421.2, J453.2, J485.2, J517.2, J549.2, J581.2, J613.2, J645.2, J677.2, J709.2, J741.2, J773.2, J805.2, J837.2, J869.2, J901.2, J933.2, J965.2, J997.2
c5: J1.31, J6.2, J38.2, J70.2, J102.2, J134.2, J166.2, J198.2, J230.2, J262.2, J294.2, J326.2, J358.2, J390.2, J422.2, J454.2, J486.2, J518.2, J550.2, J582.2, J614.2, J646.2, J678.2, J710.2, J742.2, J774.2, J806.2, J838.2, J870.2, J902.2, J934.2, J966.2, J998.2
c6: J1.30, J7.2, J39.2, J71.2, J103.2, J135.2, J167.2, J199.2, J231.2, J263.2, J295.2, J327.2, J359.2, J391.2, J423.2, J455.2, J487.2, J519.2, J551.2, J583.2, J615.2, J647.2, J679.2, J711.2, J743.2, J775.2, J807.2, J839.2, J871.2, J903.2, J935.2, J967.2, J999.2
c7: J1.29, J8.2, J40.2, J72.2, J104.2, J136.2, J168.2, J200.2, J232.2, J264.2, J296.2, J328.2, J360.2, J392.2, J424.2, J456.2, J488.2, J520.2, J552.2, J584.2, J616.2, J648.2, J680.2, J712.2, J744.2, J776.2, J808.2, J840.2, J872.2, J904.2, J936.2, J968.2, J1000.2
c8: J1.28, J9.2, J41.2, J73.2, J105.2, J137.2, J169.2, J201.2, J233.2, J265.2, J297.2, J329.2, J361.2, J393.2, J425.2, J457.2, J489.2, J521.2, J553.2, J585.2, J617.2, J649.2, J681.2, J713.2, J745.2, J777.2, J809.2, J841.2, J873.2, J905.2, J937.2, J969.2, J1001.2
c9: J1.27, J10.2, J42.2, J74.2, J106.2, J138.2, J170.2, J202.2, J234.2, J266.2, J298.2, J330.2, J362.2, J394.2, J426.2, J458.2, J490.2, J522.2, J554.2, J586.2, J618.2, J650.2, J682.2, J714.2, J746.2, J778.2, J810.2, J842.2, J874.2, J906.2, J938.2, J970.2, J1002.2
c10: J1.26, J11.2, J43.2, J75.2, J107.2, J139.2, J171.2, J203.2, J235.2, J267.2, J299.2, J331.2, J363.2, J395.2, J427.2, J459.2, J491.2, J523.2, J555.2, J587.2, J619.2, J651.2, J683.2, J715.2, J747.2, J779.2, J811.2, J843.2, J875.2, J907.2, J939.2, J971.2, J1003.2
c11: J1.25, J12.2, J44.2, J76.2, J108.2, J140.2, J172.2, J204.2, J236.2, J268.2, J300.2, J332.2, J364.2, J396.2, J428.2, J460.2, J492.2, J524.2, J556.2, J588.2, J620.2, J652.2, J684.2, J716.2, J748.2, J780.2, J812.2, J844.2, J876.2, J908.2, J940.2, J972.2, J1004.2
c12: J1.24, J13.2, J45.2, J77.2, J109.2, J141.2, J173.2, J205.2, J237.2, J269.2, J301.2, J333.2, J365.2, J397.2, J429.2, J461.2, J493.2, J525.2, J557.2, J589.2, J621.2, J653.2, J685.2, J717.2, J749.2, J781.2, J813.2, J845.2, J877.2, J909.2, J941.2, J973.2, J1005.2
c13: J1.23, J14.2, J46.2, J78.2, J110.2, J142.2, J174.2, J206.2, J238.2, J270.2, J302.2, J334.2, J366.2, J398.2, J430.2, J462.2, J494.2, J526.2, J558.2, J590.2, J622.2, J654.2, J686.2, J718.2, J750.2, J782.2, J814.2, J846.2, J878.2, J910.2, J942.2, J974.2, J1006.2
c14: J1.22, J15.2, J47.2, J79.2, J111.2, J143.2, J175.2, J207.2, J239.2, J271.2, J303.2, J335.2, J367.2, J399.2, J431.2, J463.2, J495.2, J527.2, J559.2, J591.2, J623.2, J655.2, J687.2, J719.2, J751.2, J783.2, J815.2, J847.2, J879.2, J911.2, J943.2, J975.2, J1007.2
c15: J1.21, J16.2, J48.2, J80.2, J112.2, J144.2, J176.2, J208.2, J240.2, J272.2, J304.2, J336.2, J368.2, J400.2, J432.2, J464.2, J496.2, J528.2, J560.2, J592.2, J624.2, J656.2, J688.2, J720.2, J752.2, J784.2, J816.2, J848.2, J880.2, J912.2, J944.2, J976.2, J1008.2
c16: J1.20, J17.2, J49.2, J81.2, J113.2, J145.2, J177.2, J209.2, J241.2, J273.2, J305.2, J337.2, J369.2, J401.2, J433.2, J465.2, J497.2, J529.2, J561.2, J593.2, J625.2, J657.2, J689.2, J721.2, J753.2, J785.2, J817.2, J849.2, J881.2, J913.2, J945.2, J977.2, J1009.2
c17: J1.19, J18.2, J50.2, J82.2, J114.2, J146.2, J178.2, J210.2, J242.2, J274.2, J306.2, J338.2, J370.2, J402.2, J434.2, J466.2, J498.2, J530.2, J562.2, J594.2, J626.2, J658.2, J690.2, J722.2, J754.2, J786.2, J818.2, J850.2, J882.2, J914.2, J946.2, J978.2, J1010.2
c18: J1.18, J19.2, J51.2, J83.2, J115.2, J147.2, J179.2, J211.2, J243.2, J275.2, J307.2, J339.2, J371.2, J403.2, J435.2, J467.2, J499.2, J531.2, J563.2, J595.2, J627.2, J659.2, J691.2, J723.2, J755.2, J787.2, J819.2, J851.2, J883.2, J915.2, J947.2, J979.2, J1011.2
c19: J1.17, J20.2, J52.2, J84.2, J116.2, J148.2, J180.2, J212.2, J244.2, J276.2, J308.2, J340.2, J372.2, J404.2, J436.2, J468.2, J500.2, J532.2, J564.2, J596.2, J628.2, J660.2, J692.2, J724.2, J756.2, J788.2, J820.2, J852.2, J884.2, J916.2, J948.2, J980.2, J1012.2
c20: J1.16, J21.2, J53.2, J85.2, J117.2, J149.2, J181.2, J213.2, J245.2, J277.2, J309.2, J341.2, J373.2, J405.2, J437.2, J469.2, J501.2, J533.2, J565.2, J597.2, J629.2, J661.2, J693.2, J725.2, J757.2, J789.2, J821.2, J853.2, J885.2, J917.2, J949.2, J981.2, J1013.2
c21: J1.15, J22.2, J54.2, J86.2, J118.2, J150.2, J182.2, J214.2, J246.2, J278.2, J310.2, J342.2, J374.2, J406.2, J438.2, J470.2, J502.2, J534.2, J566.2, J598.2, J630.2, J662.2, J694.2, J726.2, J758.2, J790.2, J822.2, J854.2, J886.2, J918.2, J950.2, J982.2, J1014.2
c22: J1.14, J23.2, J55.2, J87.2, J119.2, J151.2, J183.2, J215.2, J247.2, J279.2, J311.2, J343.2, J375.2, J407.2, J439.2, J471.2, J503.2, J535.2, J567.2, J599.2, J631.2, J663.2, J695.2, J727.2, J759.2, J791.2, J823.2, J855.2, J887.2, J919.2, J951.2, J983.2, J1015.2
c23: J1.13, J24.2, J56.2, J88.2, J120.2, J152.2, J184.2, J216.2, J248.2, J280.2, J312.2, J344.2, J376.2, J408.2, J440.2, J472.2, J504.2, J536.2, J568.2, J600.2, J632.2, J664.2, J696.2, J728.2, J760.2, J792.2, J824.2, J856.2, J888.2, J920.2, J952.2, J984.2, J1016.2
c24: J1.12, J25.2, J57.2, J89.2, J121.2, J153.2, J185.2, J217.2, J249.2, J281.2, J313.2, J345.2, J377.2, J409.2, J441.2, J473.2, J505.2, J537.2, J569.2, J601.2, J633.2, J665.2, J697.2, J729.2, J761.2, J793.2, J825.2, J857.2, J889.2, J921.2, J953.2, J985.2, J1017.2
c25: J1.11, J26.2, J58.2, J90.2, J122.2, J154.2, J186.2, J218.2, J250.2, J282.2, J314.2, J346.2, J378.2, J410.2, J442.2, J474.2, J506.2, J538.2, J570.2, J602.2, J634.2, J666.2, J698.2, J730.2, J762.2, J794.2, J826.2, J858.2, J890.2, J922.2, J954.2, J986.2, J1018.2
c26: J1.10, J27.2, J59.2, J91.2, J123.2, J155.2, J187.2, J219.2, J251.2, J283.2, J315.2, J347.2, J379.2, J411.2, J443.2, J475.2, J507.2, J539.2, J571.2, J603.2, J635.2, J667.2, J699.2, J731.2, J763.2, J795.2, J827.2, J859.2, J891.2, J923.2, J955.2, J987.2, J1019.2
c27: J1.9, J28.2, J60.2, J92.2, J124.2, J156.2, J188.2, J220.2, J252.2, J284.2, J316.2, J348.2, J380.2, J412.2, J444.2, J476.2, J508.2, J540.2, J572.2, J604.2, J636.2, J668.2, J700.2, J732.2, J764.2, J796.2, J828.2, J860.2, J892.2, J924.2, J956.2, J988.2, J1020.2
c28: J1.8, J29.2, J61.2, J93.2, J125.2, J157.2, J189.2, J221.2, J253.2, J285.2, J317.2, J349.2, J381.2, J413.2, J445.2, J477.2, J509.2, J541.2, J573.2, J605.2, J637.2, J669.2, J701.2, J733.2, J765.2, J797.2, J829.2, J861.2, J893.2, J925.2, J957.2, J989.2, J1021.2
c29: J1.7, J30.2, J62.2, J94.2, J126.2, J158.2, J190.2, J222.2, J254.2, J286.2, J318.2, J350.2, J382.2, J414.2, J446.2, J478.2, J510.2, J542.2, J574.2, J606.2, J638.2, J670.2, J702.2, J734.2, J766.2, J798.2, J830.2, J862.2, J894.2, J926.2, J958.2, J990.2, J1022.2
c30: J1.6, J31.2, J63.2, J95.2, J127.2, J159.2, J191.2, J223.2, J255.2, J287.2, J319.2, J351.2, J383.2, J415.2, J447.2, J479.2, J511.2, J543.2, J575.2, J607.2, J639.2, J671.2, J703.2, J735.2, J767.2, J799.2, J831.2, J863.2, J895.2, J927.2, J959.2, J991.2, J1023.2
c31: J1.5, J32.2, J64.2, J96.2, J128.2, J160.2, J192.2, J224.2, J256.2, J288.2, J320.2, J352.2, J384.2, J416.2, J448.2, J480.2, J512.2, J544.2, J576.2, J608.2, J640.2, J672.2, J704.2, J736.2, J768.2, J800.2, J832.2, J864.2, J896.2, J928.2, J960.2, J992.2, J1024.2
c32: J1.4, J33.2, J65.2, J97.2, J129.2, J161.2, J193.2, J225.2, J257.2, J289.2, J321.2, J353.2, J385.2, J417.2, J449.2, J481.2, J513.2, J545.2, J577.2, J609.2, J641.2, J673.2, J705.2, J737.2, J769.2, J801.2, J833.2, J865.2, J897.2, J929.2, J961.2, J993.2, J1025.2
r1: J1.67, J2.1, J3.1, J4.1, J5.1, J6.1, J7.1, J8.1, J9.1, J10.1, J11.1, J12.1, J13.1, J14.1, J15.1, J16.1, J17.1, J18.1, J19.1, J20.1, J21.1, J22.1, J23.1, J24.1, J25.1, J26.1, J27.1, J28.1, J29.1, J30.1, J31.1, J32.1, J33.1
r2: J1.66, J34.1, J35.1, J36.1, J37.1, J38.1, J39.1, J40.1, J41.1, J42.1, J43.1, J44.1, J45.1, J46.1, J47.1, J48.1, J49.1, J50.1, J51.1, J52.1, J53.1, J54.1, J55.1, J56.1, J57.1, J58.1, J59.1, J60.1, J61.1, J62.1, J63.1, J64.1, J65.1
r3: J1.65, J66.1, J67.1, J68.1, J69.1, J70.1, J71.1, J72.1, J73.1, J74.1, J75.1, J76.1, J77.1, J78.1, J79.1, J80.1, J81.1, J82.1, J83.1, J84.1, J85.1, J86.1, J87.1, J88.1, J89.1, J90.1, J91.1, J92.1, J93.1, J94.1, J95.1, J96.1, J97.1
r4: J1.64, J98.1, J99.1, J100.1, J101.1, J102.1, J103.1, J104.1, J105.1, J106.1, J107.1, J108.1, J109.1, J110.1, J111.1, J112.1, J113.1, J114.1, J115.1, J116.1, J117.1, J118.1, J119.1, J120.1, J121.1, J122.1, J123.1, J124.1, J125.1, J126.1, J127.1, J128.1, J129.1
r5: J1.63, J130.1, J131.1, J132.1, J133.1, J134.1, J135.1, J136.1, J137.1, J138.1, J139.1, J140.1, J141.1, J142.1, J143.1, J144.1, J145.1, J146.1, J147.1, J148.1, J149.1, J150.1, J151.1, J152.1, J153.1, J154.1, J155.1, J156.1, J157.1, J158.1, J159.1, J160.1, J161.1
r6: J1.62, J162.1, J163.1, J164.1, J165.1, J166.1, J167.1, J168.1, J169.1, J170.1, J171.1, J172.1, J173.1, J174.1, J175.1, J176.1, J177.1, J178.1, J179.1, J180.1, J181.1, J182.1, J183.1, J184.1, J185.1, J186.1, J187.1, J188.1, J189.1, J190.1, J191.1, J192.1, J193.1
r7: J1.61, J194.1, J195.1, J196.1, J197.1, J198.1, J199.1, J200.1, J201.1, J202.1, J203.1, J204.1, J205.1, J206.1, J207.1, J208.1, J209.1, J210.1, J211.1, J212.1, J213.1, J214.1, J215.1, J216.1, J217.1, J218.1, J219.1, J220.1, J221.1, J222.1, J223.1, J224.1, J225.1
r8: J1.60, J226.1, J227.1, J228.1, J229.1, J230.1, J231.1, J232.1, J233.1, J234.1, J235.1, J236.1, J237.1, J238.1, J239.1, J240.1, J241.1, J242.1, J243.1, J244.1, J245.1, J246.1, J247.1, J248.1, J249.1, J250.1, J251.1, J252.1, J253.1, J254.1, J255.1, J256.1, J257.1
r9: J1.59, J258.1, J259.1, J260.1, J261.1, J262.1, J263.1, J264.1, J265.1, J266.1, J267.1, J268.1, J269.1, J270.1, J271.1, J272.1, J273.1, J274.1, J275.1, J276.1, J277.1, J278.1, J279.1, J280.1, J281.1, J282.1, J283.1, J284.1, J285.1, J286.1, J287.1, J288.1, J289.1
r10: J1.58, J290.1, J291.1, J292.1, J293.1, J294.1, J295.1, J296.1, J297.1, J298.1, J299.1, J300.1, J301.1, J302.1, J303.1, J304.1, J305.1, J306.1, J307.1, J308.1, J309.1, J310.1, J311.1, J312.1, J313.1, J314.1, J315.1, J316.1, J317.1, J318.1, J319.1, J320.1, J321.1
r11: J1.57, J322.1, J323.1, J324.1, J325.1, J326.1, J327.1, J328.1, J329.1, J330.1, J331.1, J332.1, J333.1, J334.1, J335.1, J336.1, J337.1, J338.1, J339.1, J340.1, J341.1, J342.1, J343.1, J344.1, J345.1, J346.1, J347.1, J348.1, J349.1, J350.1, J351.1, J352.1, J353.1
r12: J1.56, J354.1, J355.1, J356.1, J357.1, J358.1, J359.1, J360.1, J361.1, J362.1, J363.1, J364.1, J365.1, J366.1, J367.1, J368.1, J369.1, J370.1, J371.1, J372.1, J373.1, J374.1, J375.1, J376.1, J377.1, J378.1, J379.1, J380.1, J381.1, J382.1, J383.1, J384.1, J385.1
r13: J1.55, J386.1, J387.1, J388.1, J389.1, J390.1, J391.1, J392.1, J393.1, J394.1, J395.1, J396.1, J397.1, J398.1, J399.1, J400.1, J401.1, J402.1, J403.1, J404.1, J405.1, J406.1, J407.1, J408.1, J409.1, J410.1, J411.1, J412.1, J413.1, J414.1, J415.1, J416.1, J417.1
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

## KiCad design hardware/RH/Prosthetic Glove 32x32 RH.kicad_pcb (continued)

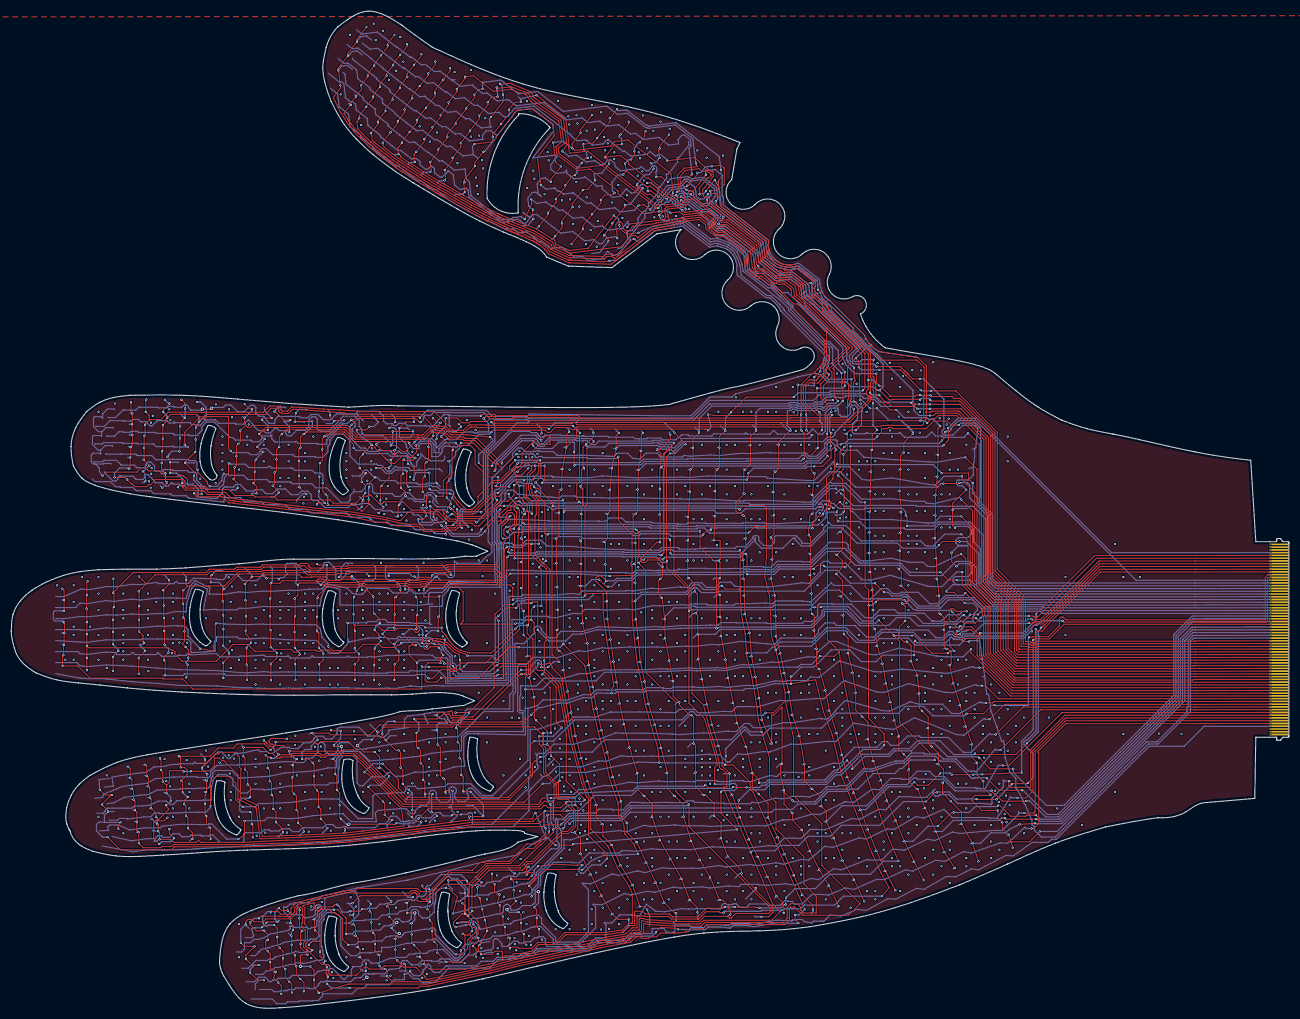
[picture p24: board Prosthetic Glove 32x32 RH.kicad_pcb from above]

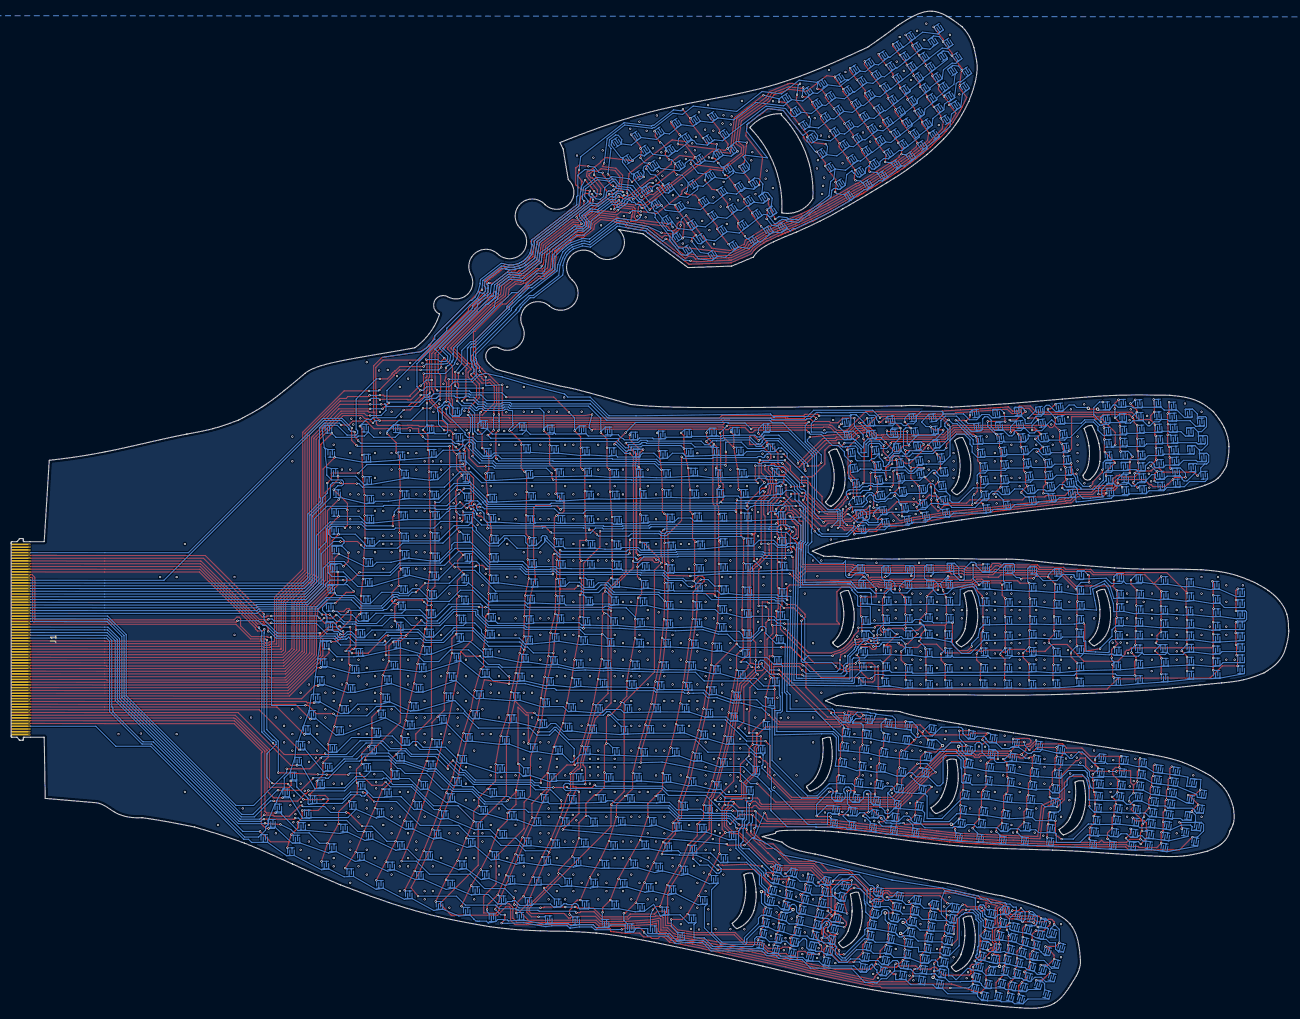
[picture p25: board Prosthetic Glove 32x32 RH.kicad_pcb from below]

Board: 2 copper layers, 231.9 x 181.0 mm, 1025 parts (1025 on the bottom side), 65 nets.

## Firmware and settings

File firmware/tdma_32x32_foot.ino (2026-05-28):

// 32x32 raster scan of TDMA sensor
// Compile for Teensy 4.1
// Digital pins are d0 through d13, and then d15 through d32
// Analog pin is a0
// Mux pins are d33 through d37 | mux0-4

const int N = 1024; //number of sensors; 32*32
int values[N]; //variable to save values of the array
int idx = 0;
unsigned long timer1;


// what are the connected digital pins?
int dpins[32] = {0, 1, 2, 3, 4, 5, 6, 7, 8, 9, 10, 11, 12, 13, 15, 16, 17, 18, 19, 20, 21, 22, 23, 24, 25, 26, 27, 28, 29, 30, 31, 32};

int muxtable[32][5] = {
  {0, 0, 0, 0, 0},
  {0, 0, 0, 0, 1},
  {0, 0, 0, 1, 0},
  {0, 0, 0, 1, 1},
  {0, 0, 1, 0, 0},
  {0, 0, 1, 0, 1},
  {0, 0, 1, 1, 0},
  {0, 0, 1, 1, 1},
  {0, 1, 0, 0, 0},
  {0, 1, 0, 0, 1},
  {0, 1, 0, 1, 0},
  {0, 1, 0, 1, 1},
  {0, 1, 1, 0, 0},
  {0, 1, 1, 0, 1},
  {0, 1, 1, 1, 0},
  {0, 1, 1, 1, 1},
  {1, 0, 0, 0, 0},
  {1, 0, 0, 0, 1},
  {1, 0, 0, 1, 0},
  {1, 0, 0, 1, 1},
  {1, 0, 1, 0, 0},
  {1, 0, 1, 0, 1},
  {1, 0, 1, 1, 0},
  {1, 0, 1, 1, 1},
  {1, 1, 0, 0, 0},
  {1, 1, 0, 0, 1},
  {1, 1, 0, 1, 0},
  {1, 1, 0, 1, 1},
  {1, 1, 1, 0, 0},
  {1, 1, 1, 0, 1},
  {1, 1, 1, 1, 0},
  {1, 1, 1, 1, 1},
};

void setup() {

  for (int i = 0; i < 32; i++) { //rows
    pinMode(dpins[i], OUTPUT);
  }

  //mux pins
  pinMode(33, OUTPUT);
  pinMode(34, OUTPUT);
  pinMode(35, OUTPUT);
  pinMode(36, OUTPUT);
  pinMode(37, OUTPUT);

  //set all the output pins to low
  for (int i = 0; i < 32; i++) {
    digitalWriteFast(dpins[i], LOW);
  }
}

FASTRUN void loop() {
  // put your main code here, to run repeatedly:
  timer1 = micros();
  idx = 0;
  for (int i = 0; i < 32; i++) { //loop through the output rows
    //pinMode(dpins[i], OUTPUT);
    digitalWriteFast(dpins[i], HIGH);
    for (int j = 0; j < 32; j++) {
      // multiplex the readout columns
      digitalWriteFast(37, muxtable[j][0]);
      digitalWriteFast(36, muxtable[j][1]);
      digitalWriteFast(35, muxtable[j][2]);
      digitalWriteFast(34, muxtable[j][3]);
      digitalWriteFast(33, muxtable[j][4]);
      //delayMicroseconds(5);
      values[idx] = analogRead(A0);
      idx = idx + 1;
    }
    digitalWriteFast(dpins[i], LOW); // turn that row back to low
  }
  timer1 = micros() - timer1;

  for (int q = 0; q < N; q++) { //print out the values to serial monitor
    Serial.print(values[q]);
    Serial.print(',');
    delayMicroseconds(5);
  }
  //Serial.print(timer1);
  Serial.println();
}
